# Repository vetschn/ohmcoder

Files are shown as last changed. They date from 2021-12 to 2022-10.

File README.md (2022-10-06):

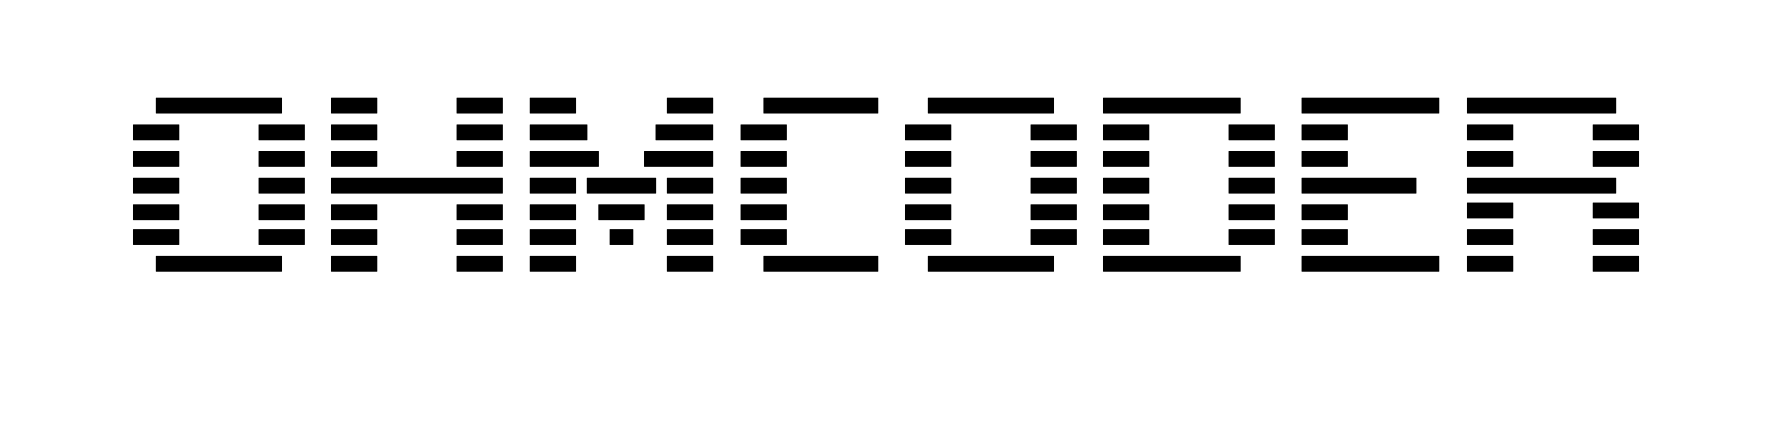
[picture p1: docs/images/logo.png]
ohmcoder
# 

The `OHMCODER` is a 16 channel fully analog vocoder, housed in a 3U 19"
enclosure with a full patch bay and feed-through functionality.

This project is inspired by [this](https://www.instructables.com/Build-an-analog-vocoder/) instructables project by user [planetone](https://www.instructables.com/member/planetone/).

## Overview

In vocoders, a program and carrier signal are filtered into a number of
frequency bands. The envelope of the program signal bands then modulates
the carrier signal bands. Finally, the per-band contributions are summed
back together to get the vocoded output.

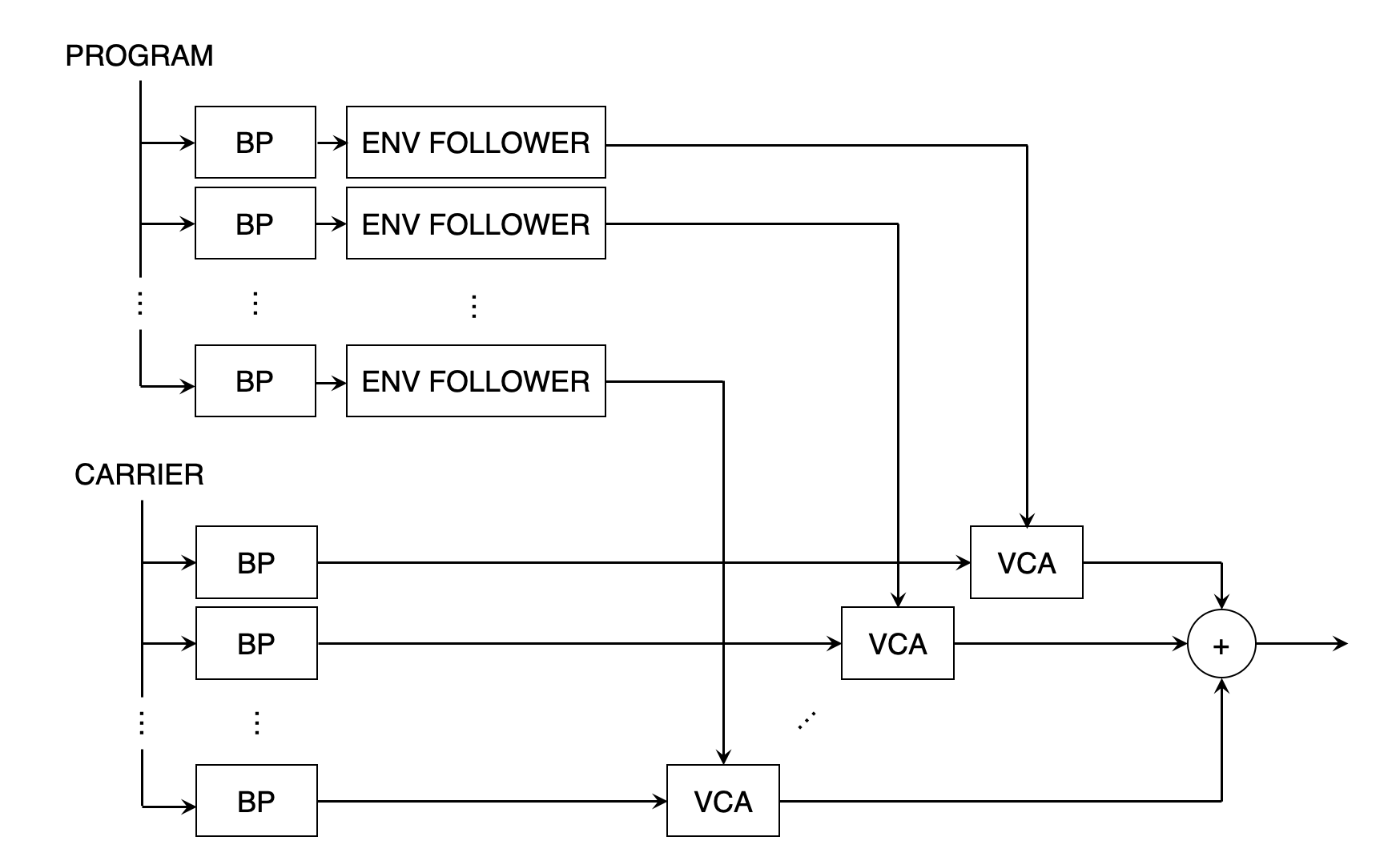
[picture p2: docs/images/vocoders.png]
vocoders


The core of the design thus made up of

- [Bandpass Filters](#multiple-feedback-infinite-gain-bandpass-filters)
- [Envelope Followers](#envelope-followers)
- [Voltage Controlled Amplifiers](#ota-voltage-controlled-amplifiers)

## Features

<!-- TODO -->

- Jack and XLR Input
- Patch Bay
- Per-Band Gain Control with LED Indicators
- Program or Carrier Band Feed-Through and/or Mixing
- Stereo and Mono Jack Output

## Circuits

### Multiple-Feedback Infinite Gain Bandpass Filters

We used the same second order multiple-feedback infinite-gain active
bandpass filters as in the instructibles project. TL074 quad opamps are
used.

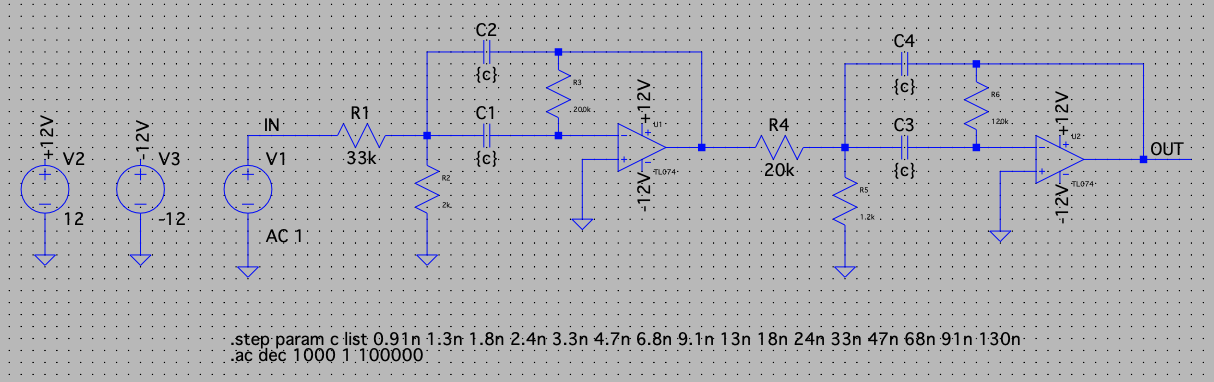
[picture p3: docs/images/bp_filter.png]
bp_filter


Notice, that the nice thing about these filters is, that we only need to
change the capacitor values to get different center frequencies, as seen
in the SPICE simulation below.

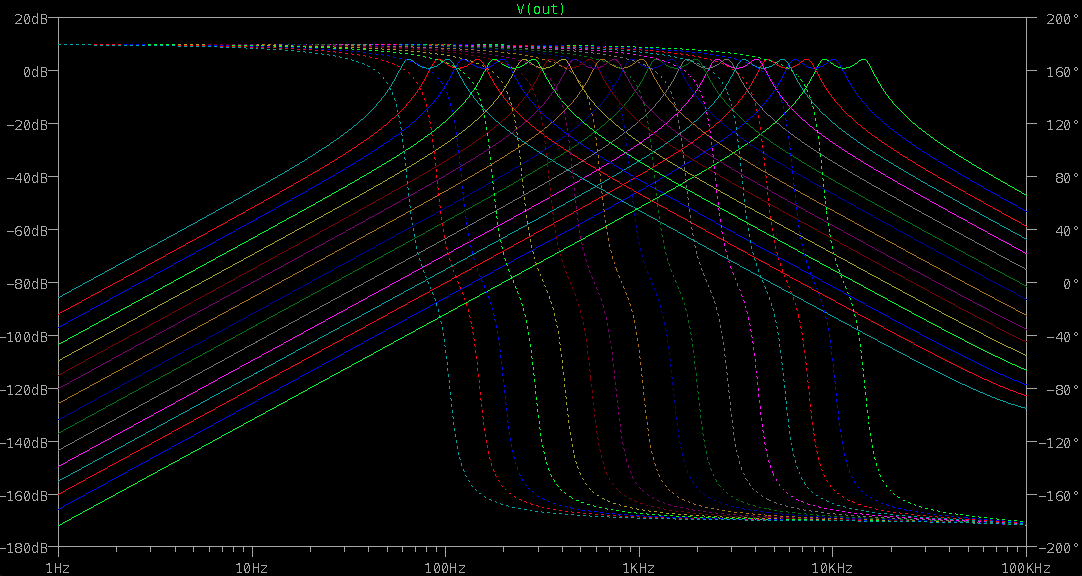
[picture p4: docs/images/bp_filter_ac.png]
bp_filter_ac


#### Capacitor Values

| Band | f_low [Hz] | f_high [Hz] | C [nF] |
| ---- | --- | --- | --- |
| 01 | 65 | 105 | 0.91 |
| 02 | 90 | 150 | 1.3 |
| 03 | 125 | 200 | 1.8 |
| 04 | 175 | 285 | 2.4 |
| 05 | 255 | 400 | 3.3 |
| 06 | 345 | 555 | 4.7 |
| 07 | 465 | 755 | 6.8 |
| 08 | 635 | 1050 | 9.1 |
| 09 | 920 | 1455 | 13 |
| 10 | 1220 | 1960 | 18 |
| 11 | 1765 | 2880 | 24 |
| 12 | 2500 | 4075 | 33 |
| 13 | 3515 | 5605 | 47 |
| 14 | 4640 | 7550 | 68 |
| 15 | 6375 | 10375 | 91 |
| 16 | 9200 | 15000 | 130 |

### Envelope Followers

This is where we depart from planetone's design. We use a low-pass
filtered precision rectifier signal to follow the program envelope.

The majority of the spectral energy of speech amplitude modulation lies
below about 15Hz, i. e. the mean time between syllables is about
1/15Hz (see [speech_modulation.ipynb](./auxiliary/notebooks/speech_modulation.ipynb) for an example). The filter is chosen such that we follow this
amplitude modulation.

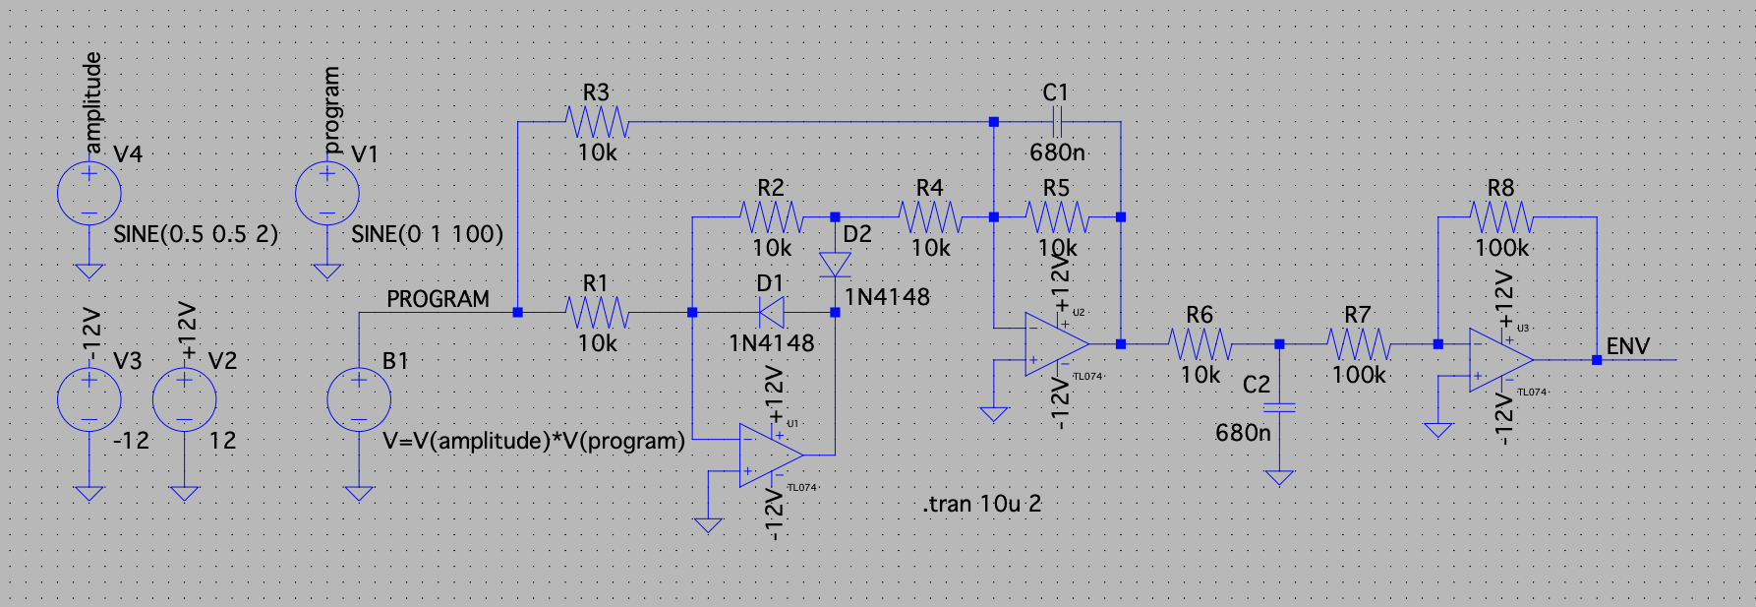
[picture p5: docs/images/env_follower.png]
env_follower


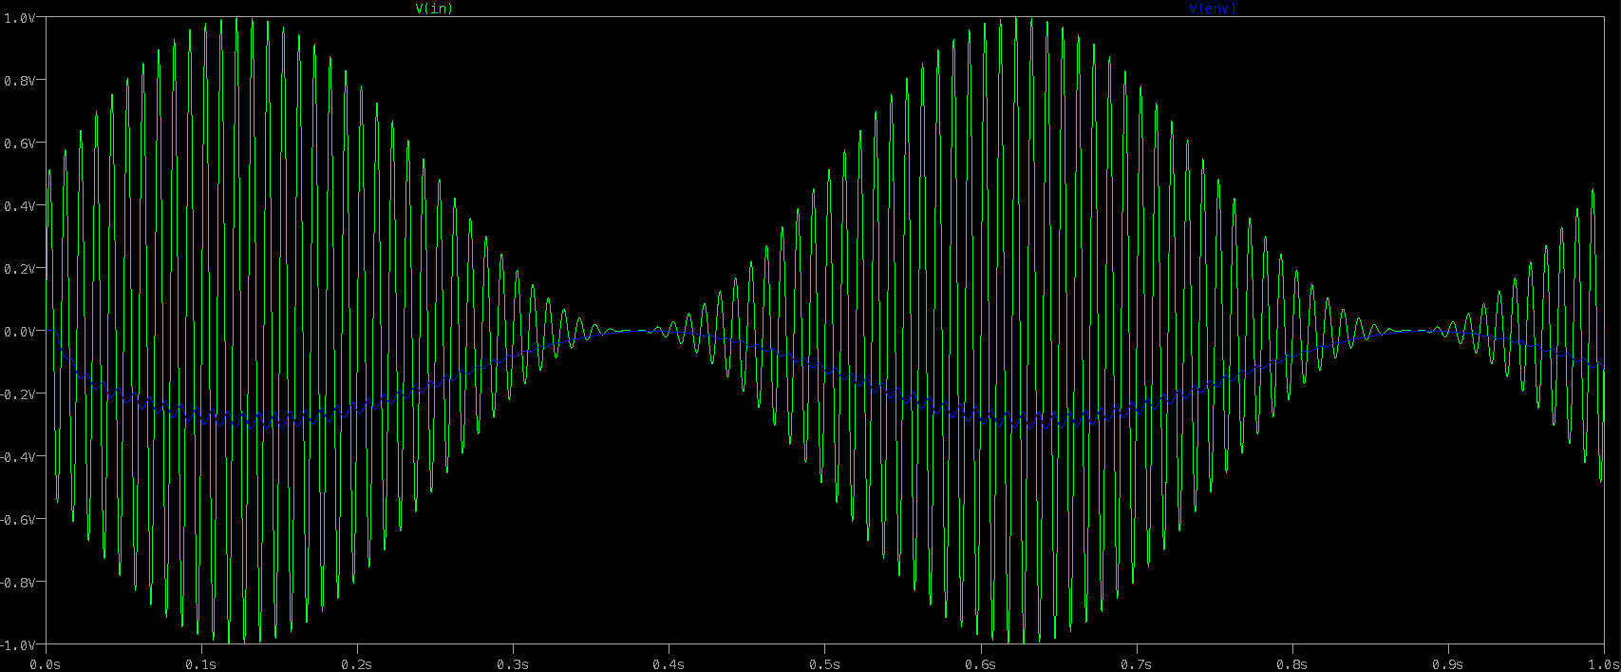
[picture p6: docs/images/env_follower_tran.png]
env_follower_tran


### OTA Voltage Controlled Amplifiers

We use VCAs based on the LM13700 quad operational transconductance
amplifier, making use of its linearizing diodes and the integrated
buffer circuits.

The program envelope controls the amplifier gain via a voltage to
current converter circuit.

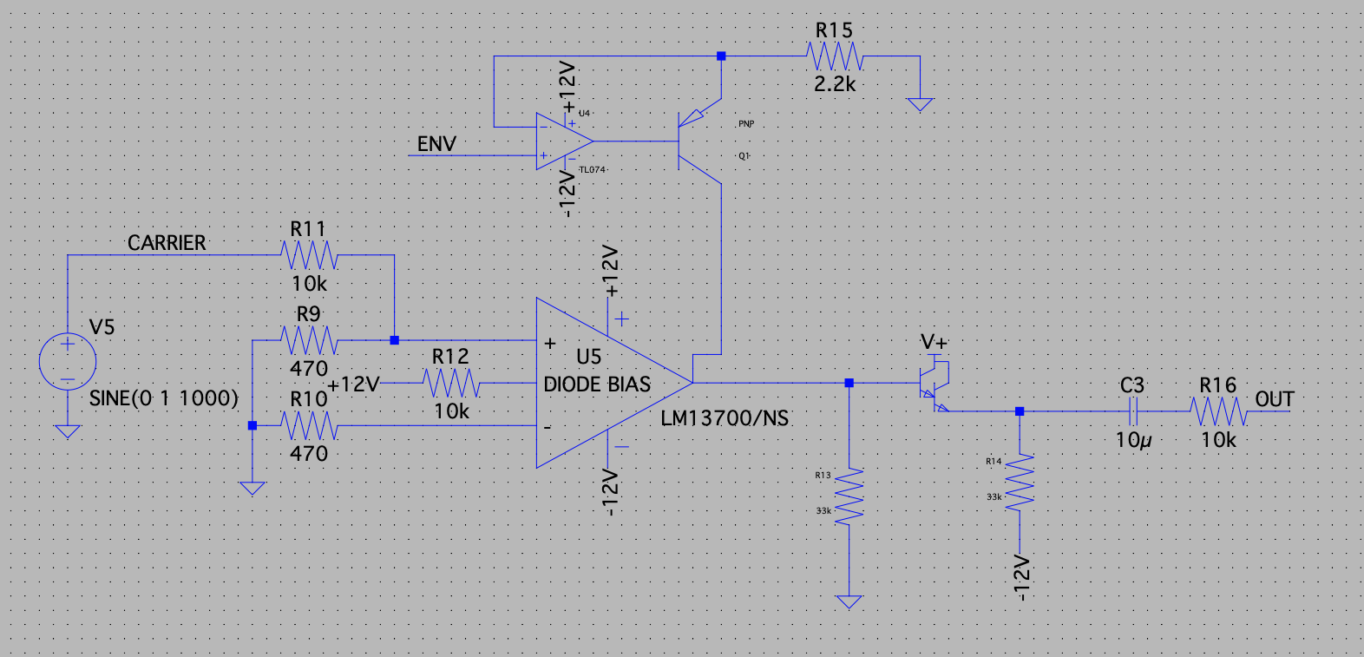
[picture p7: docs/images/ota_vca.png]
ota_vca


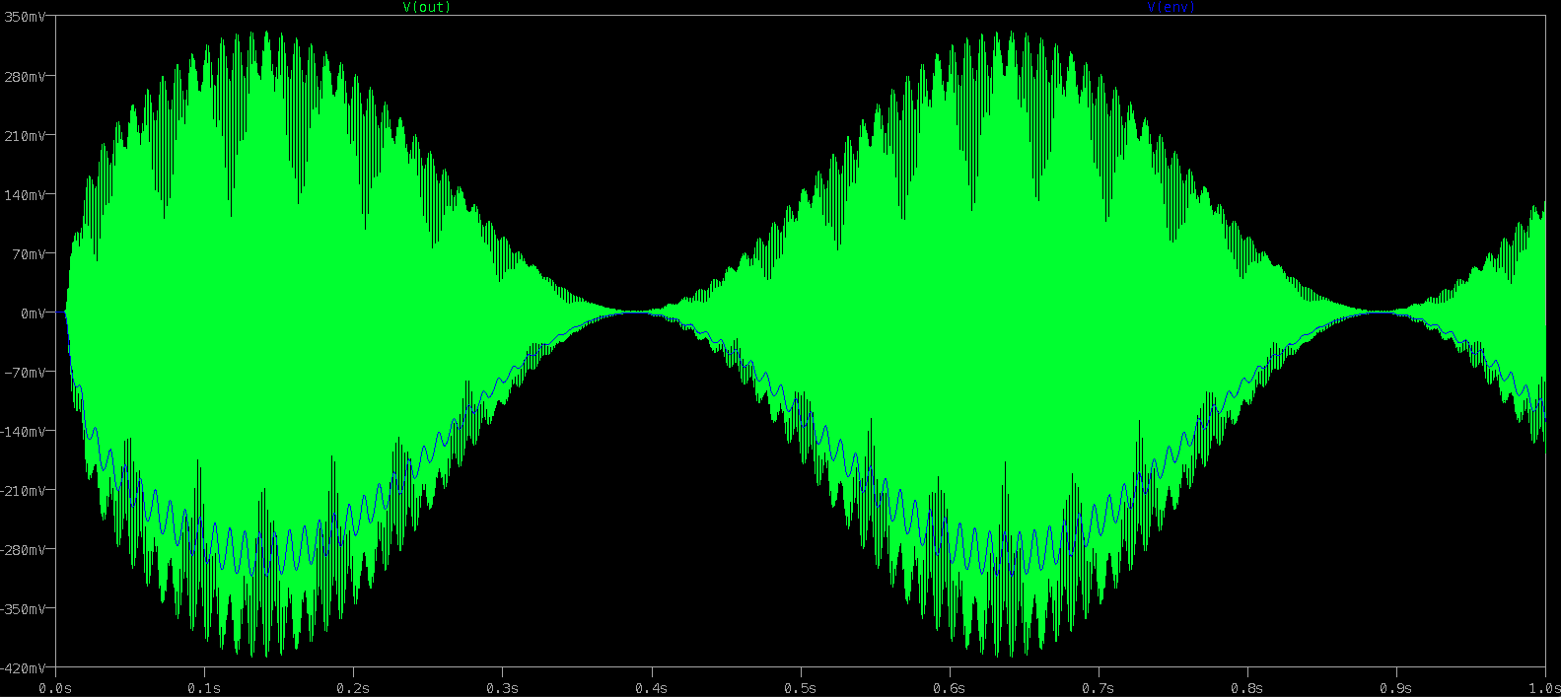
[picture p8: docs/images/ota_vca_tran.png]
ota_vca_tran


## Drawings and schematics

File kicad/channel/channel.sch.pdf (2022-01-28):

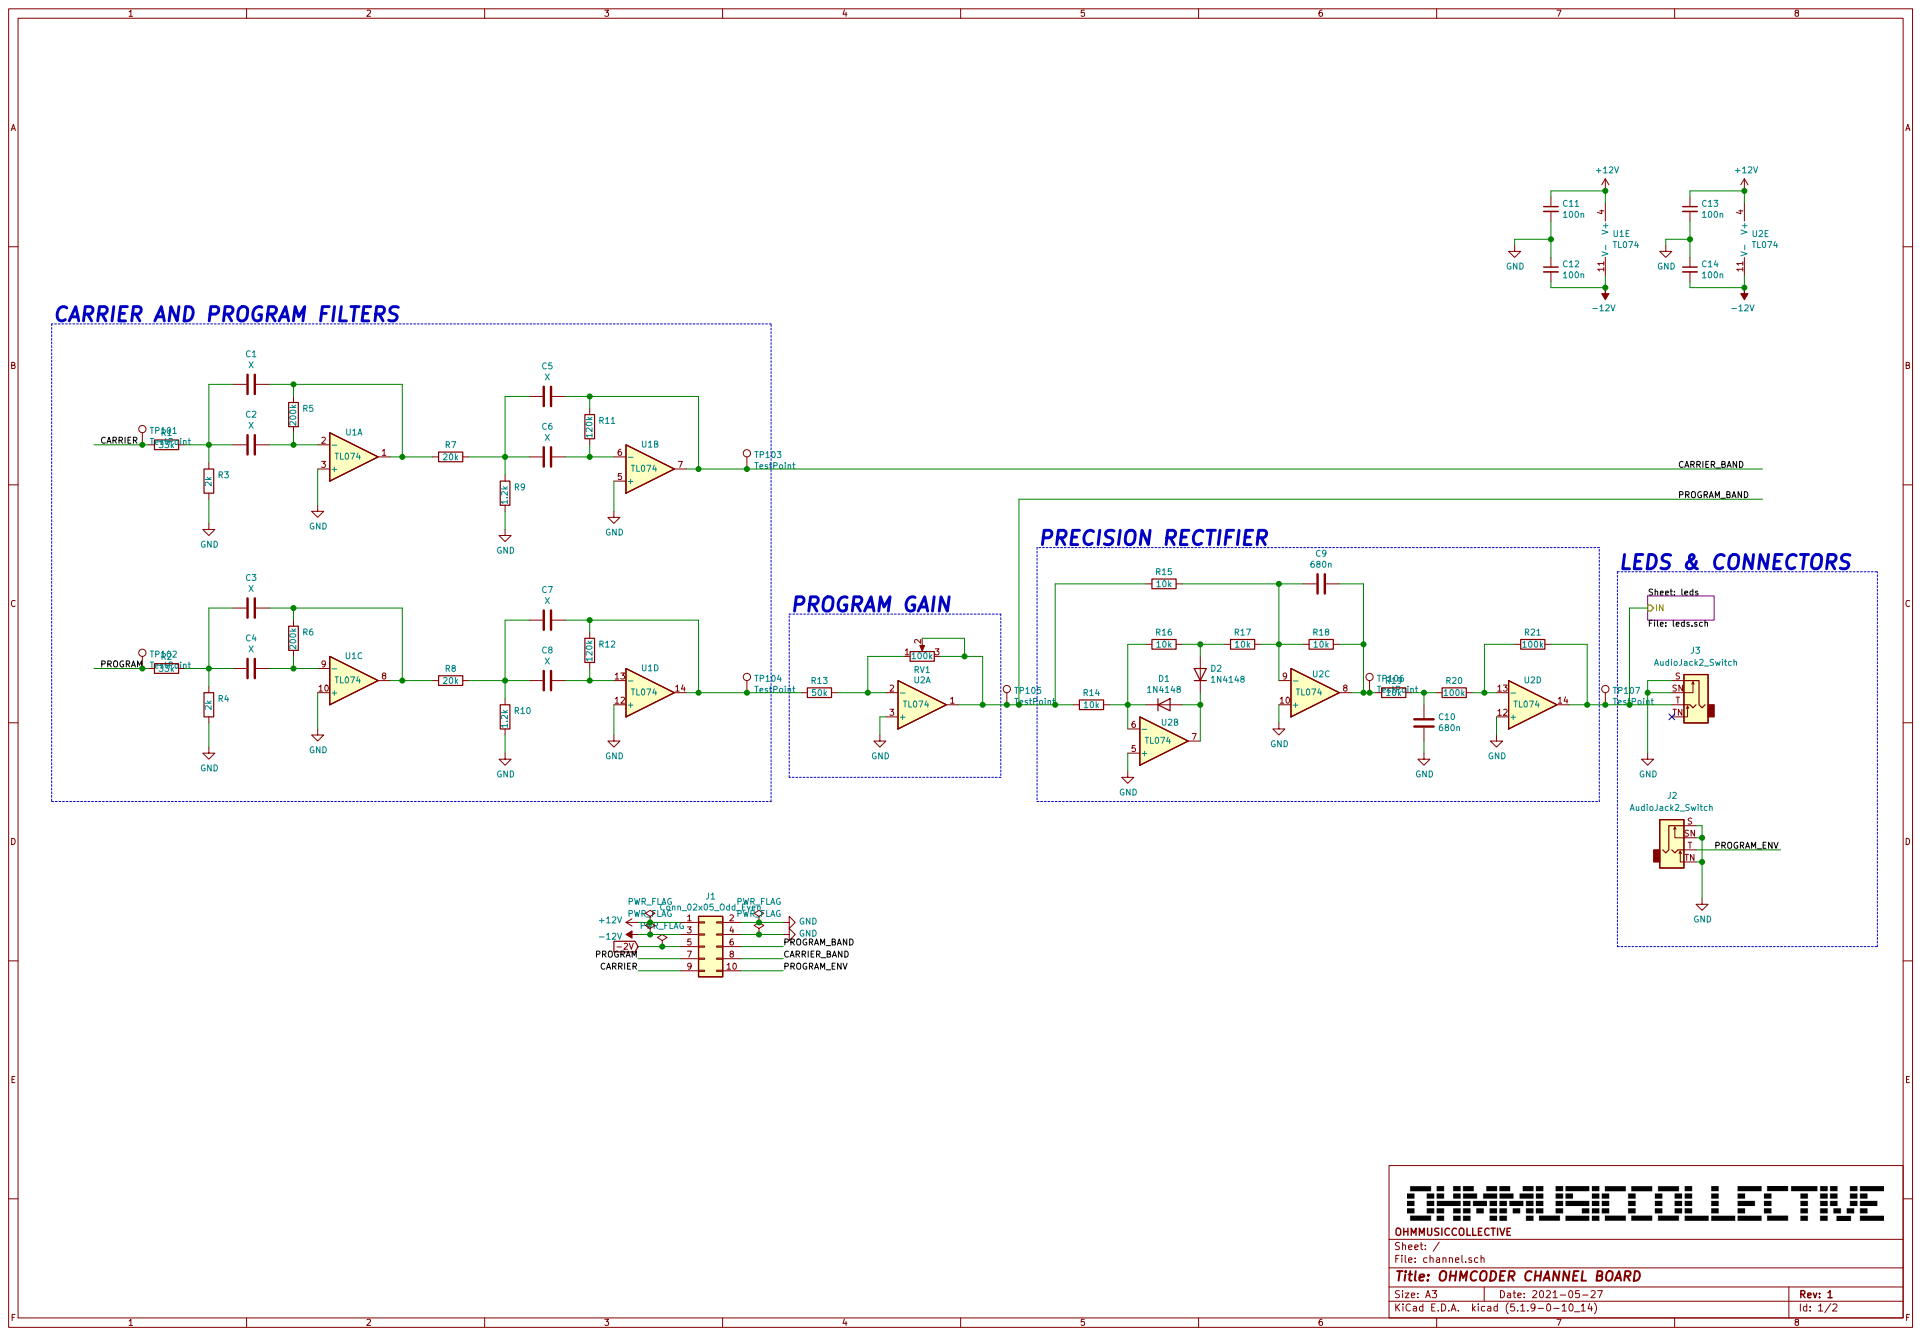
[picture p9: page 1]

PROGRAM_BAND CARRIER AND PROGRAM FILTERS

Sheet: leds File: leds.sch

File: channel.sch Sheet: / OHMMUSICCOLLECTIVE

Id: 1/2 Title: OHMCODER CHANNEL BOARD

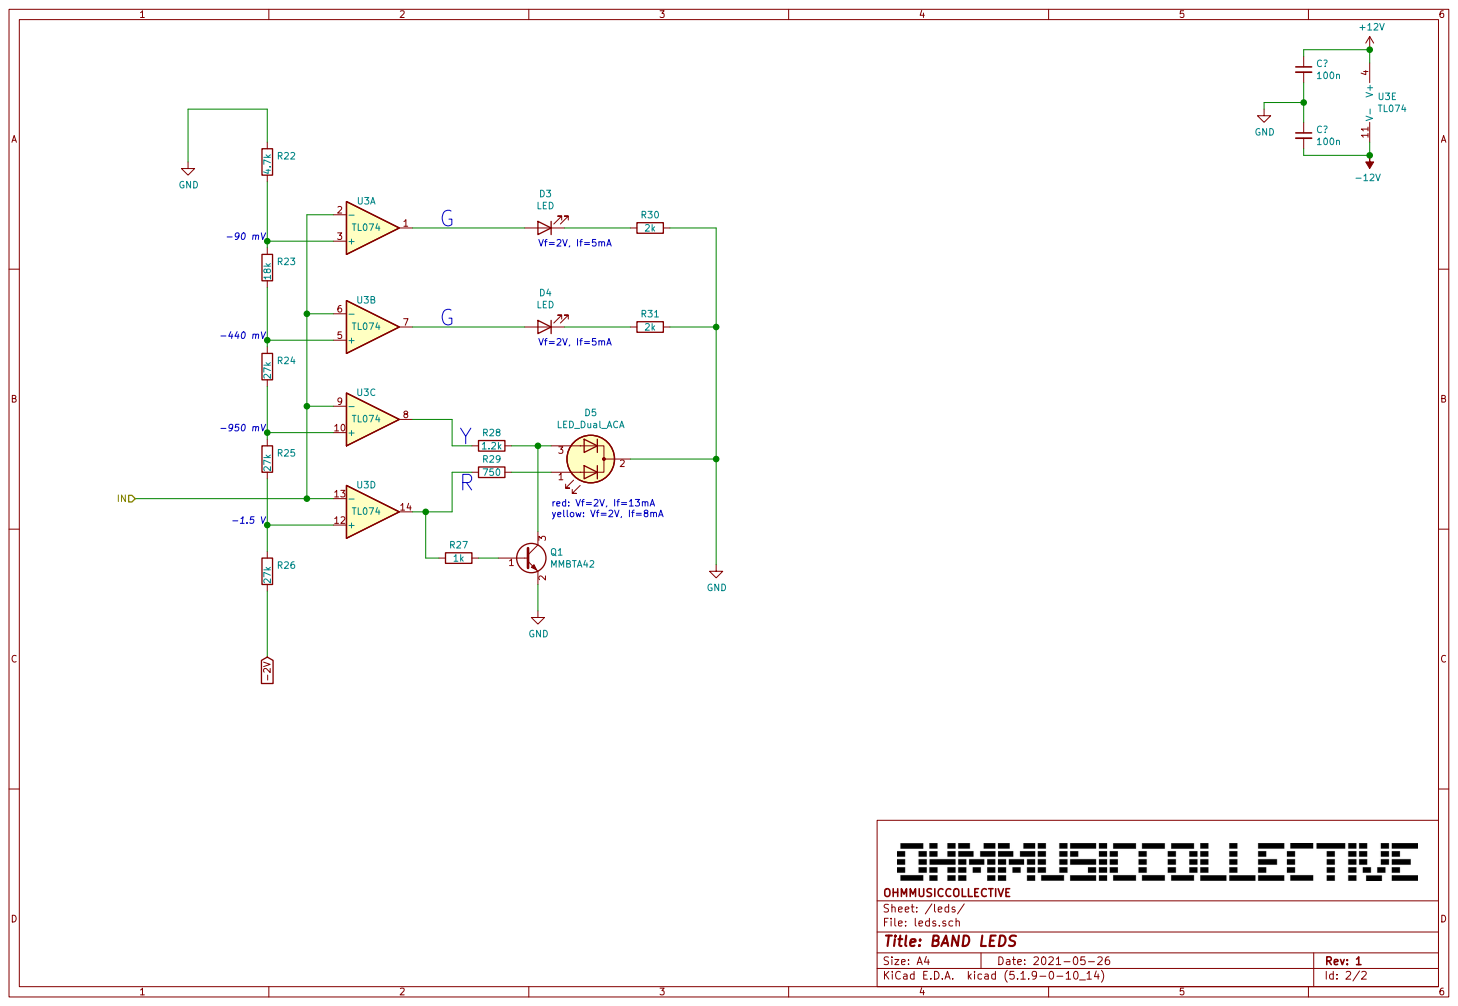
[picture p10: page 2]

File: leds.sch Sheet: /leds/ OHMMUSICCOLLECTIVE

Id: 2/2 Title: BAND LEDS

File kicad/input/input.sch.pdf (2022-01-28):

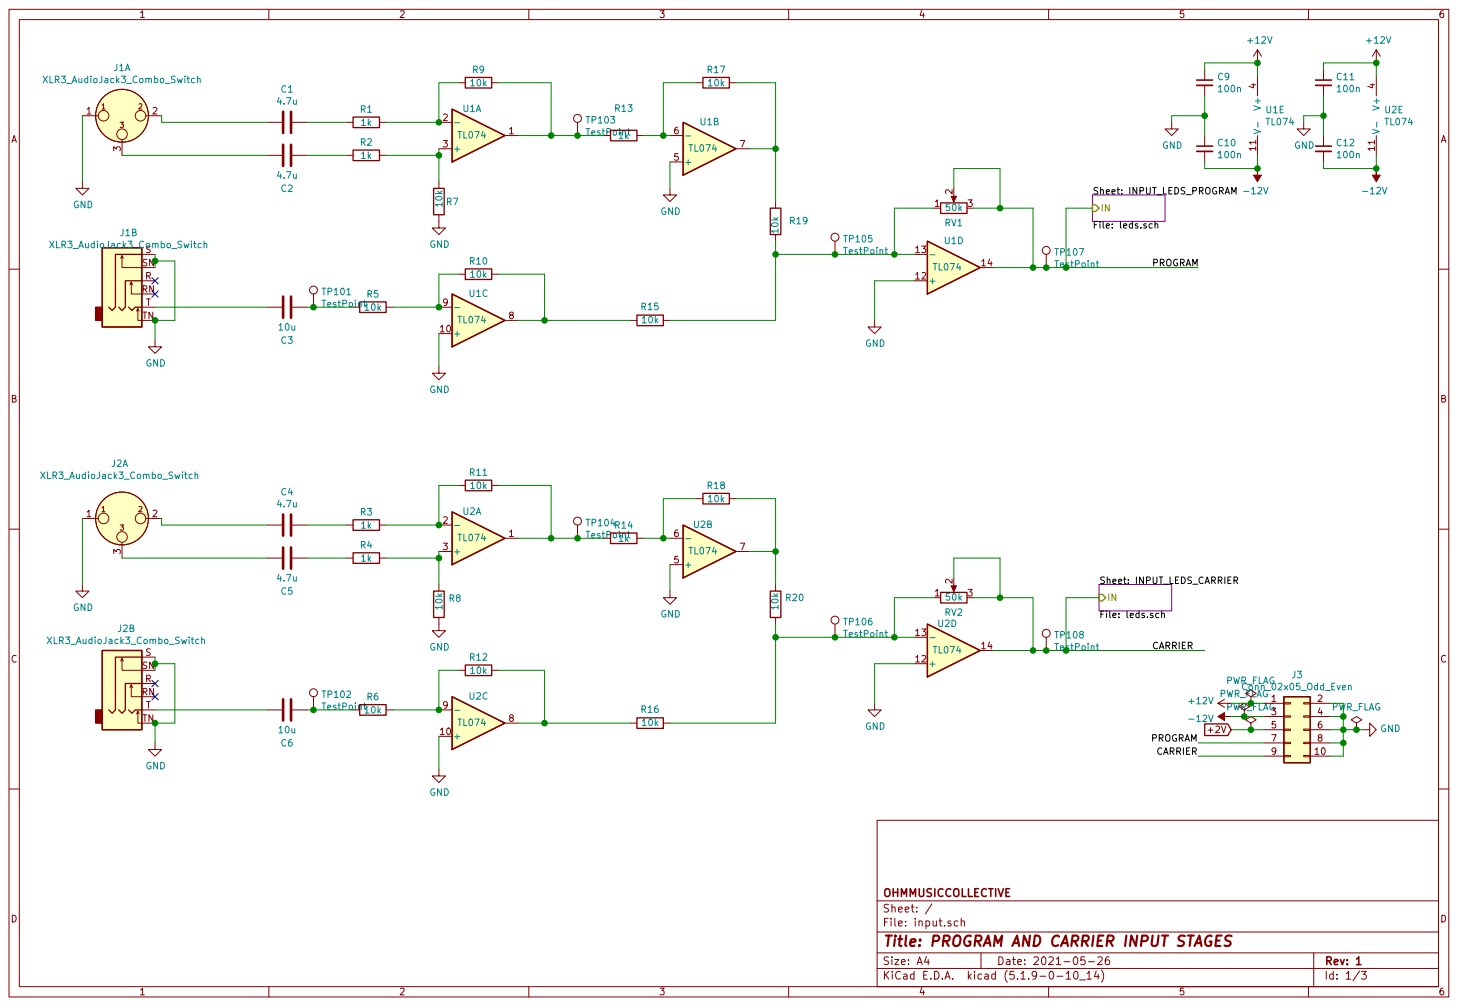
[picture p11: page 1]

File: input.sch Sheet: / OHMMUSICCOLLECTIVE

Id: 1/3 Title: PROGRAM AND CARRIER INPUT STAGES

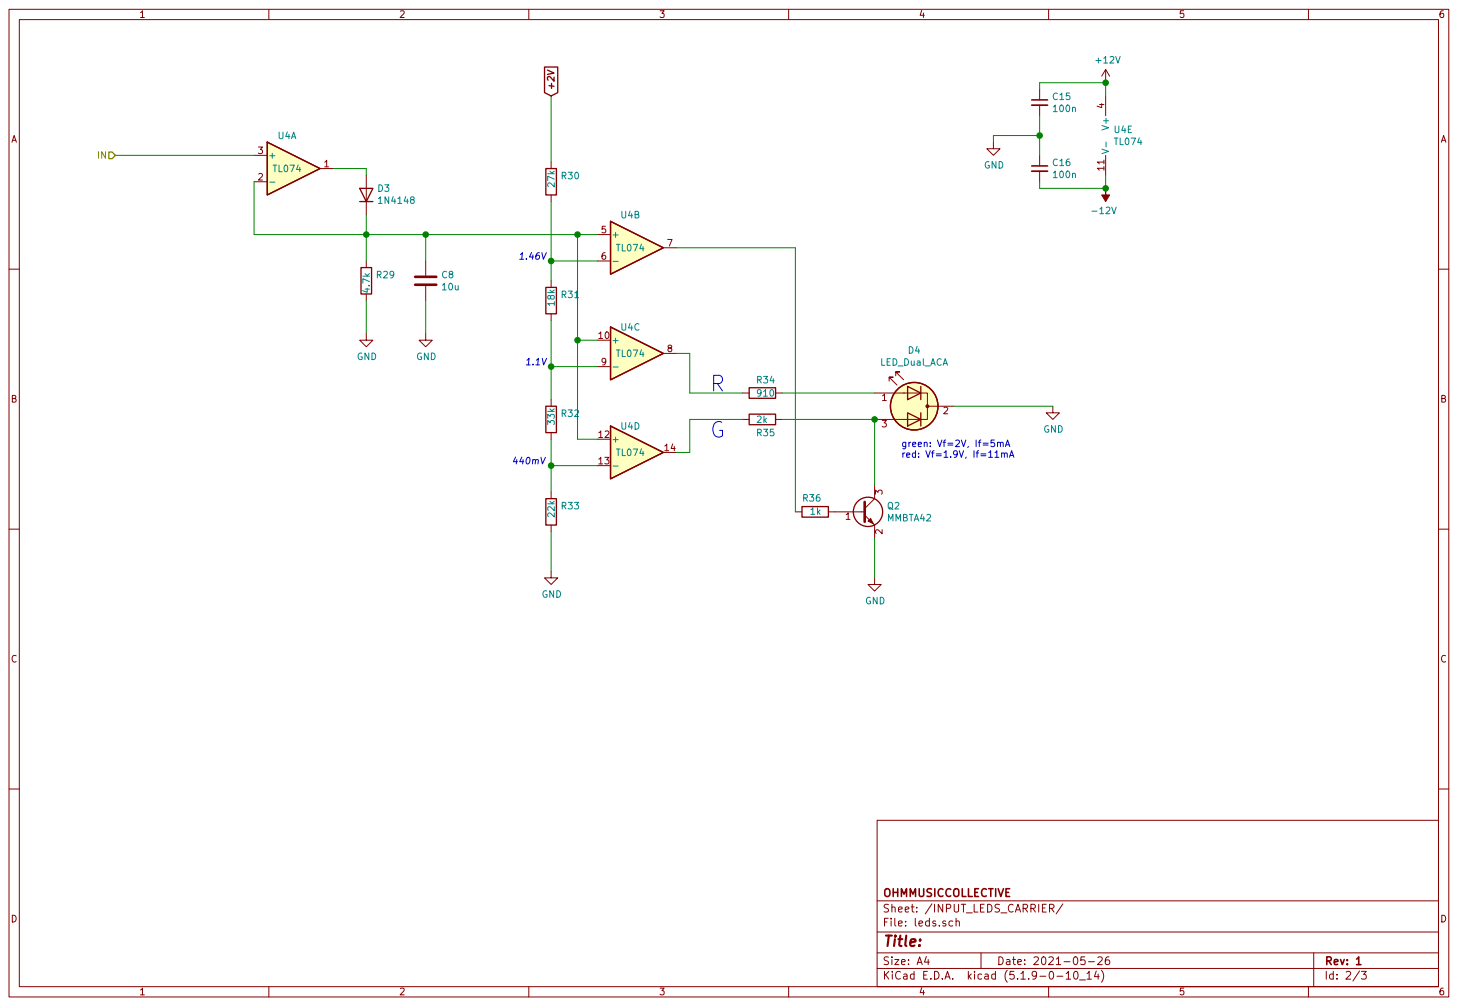
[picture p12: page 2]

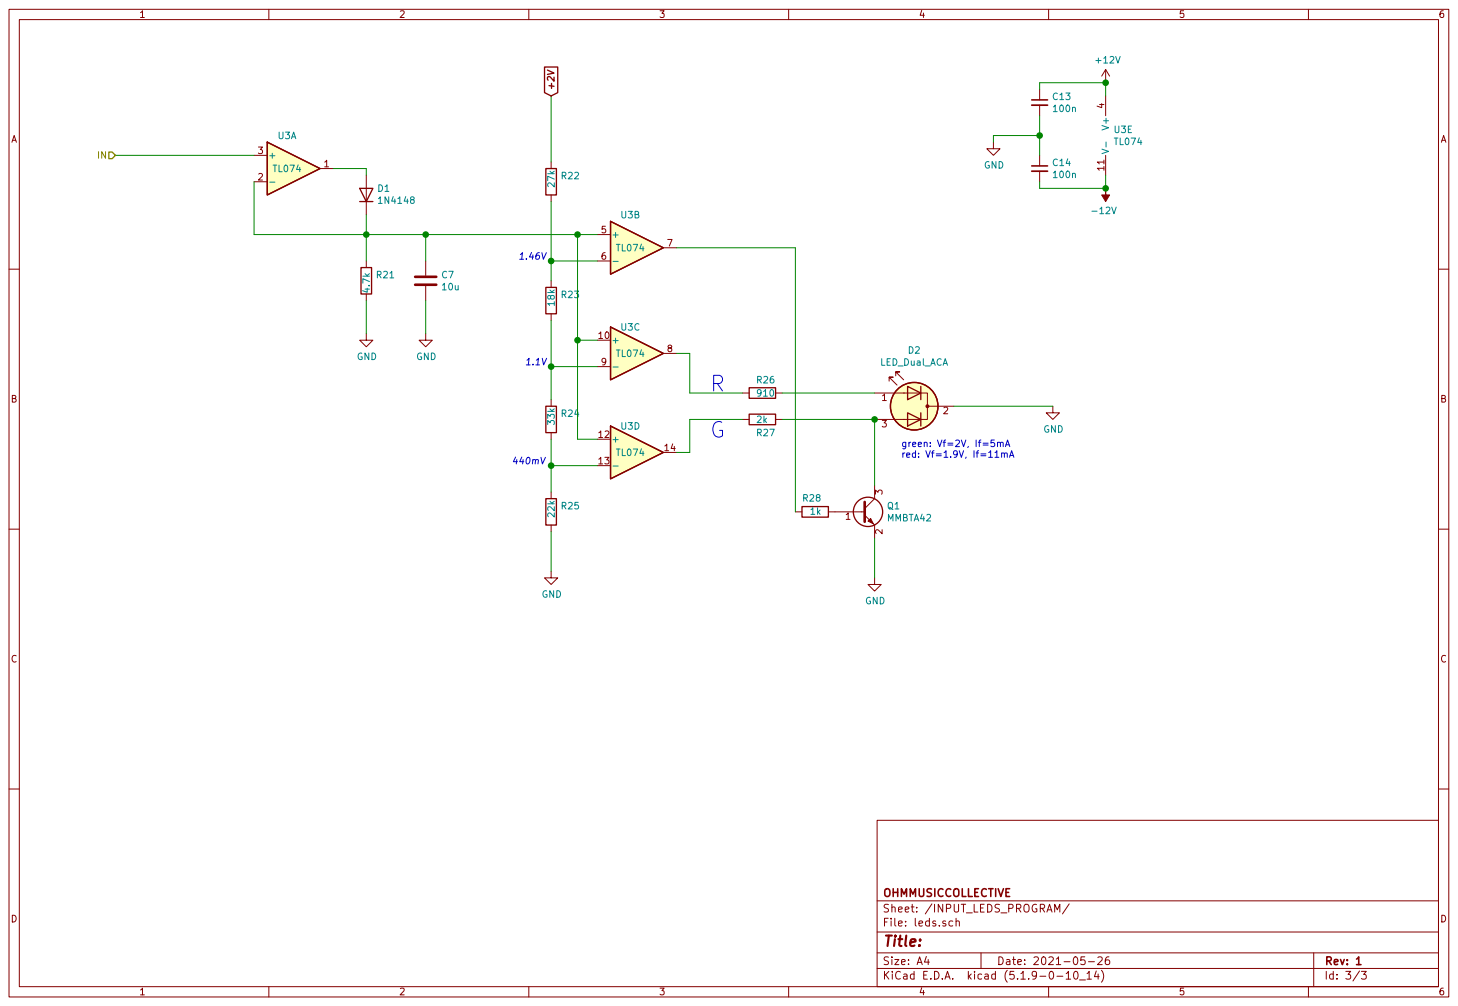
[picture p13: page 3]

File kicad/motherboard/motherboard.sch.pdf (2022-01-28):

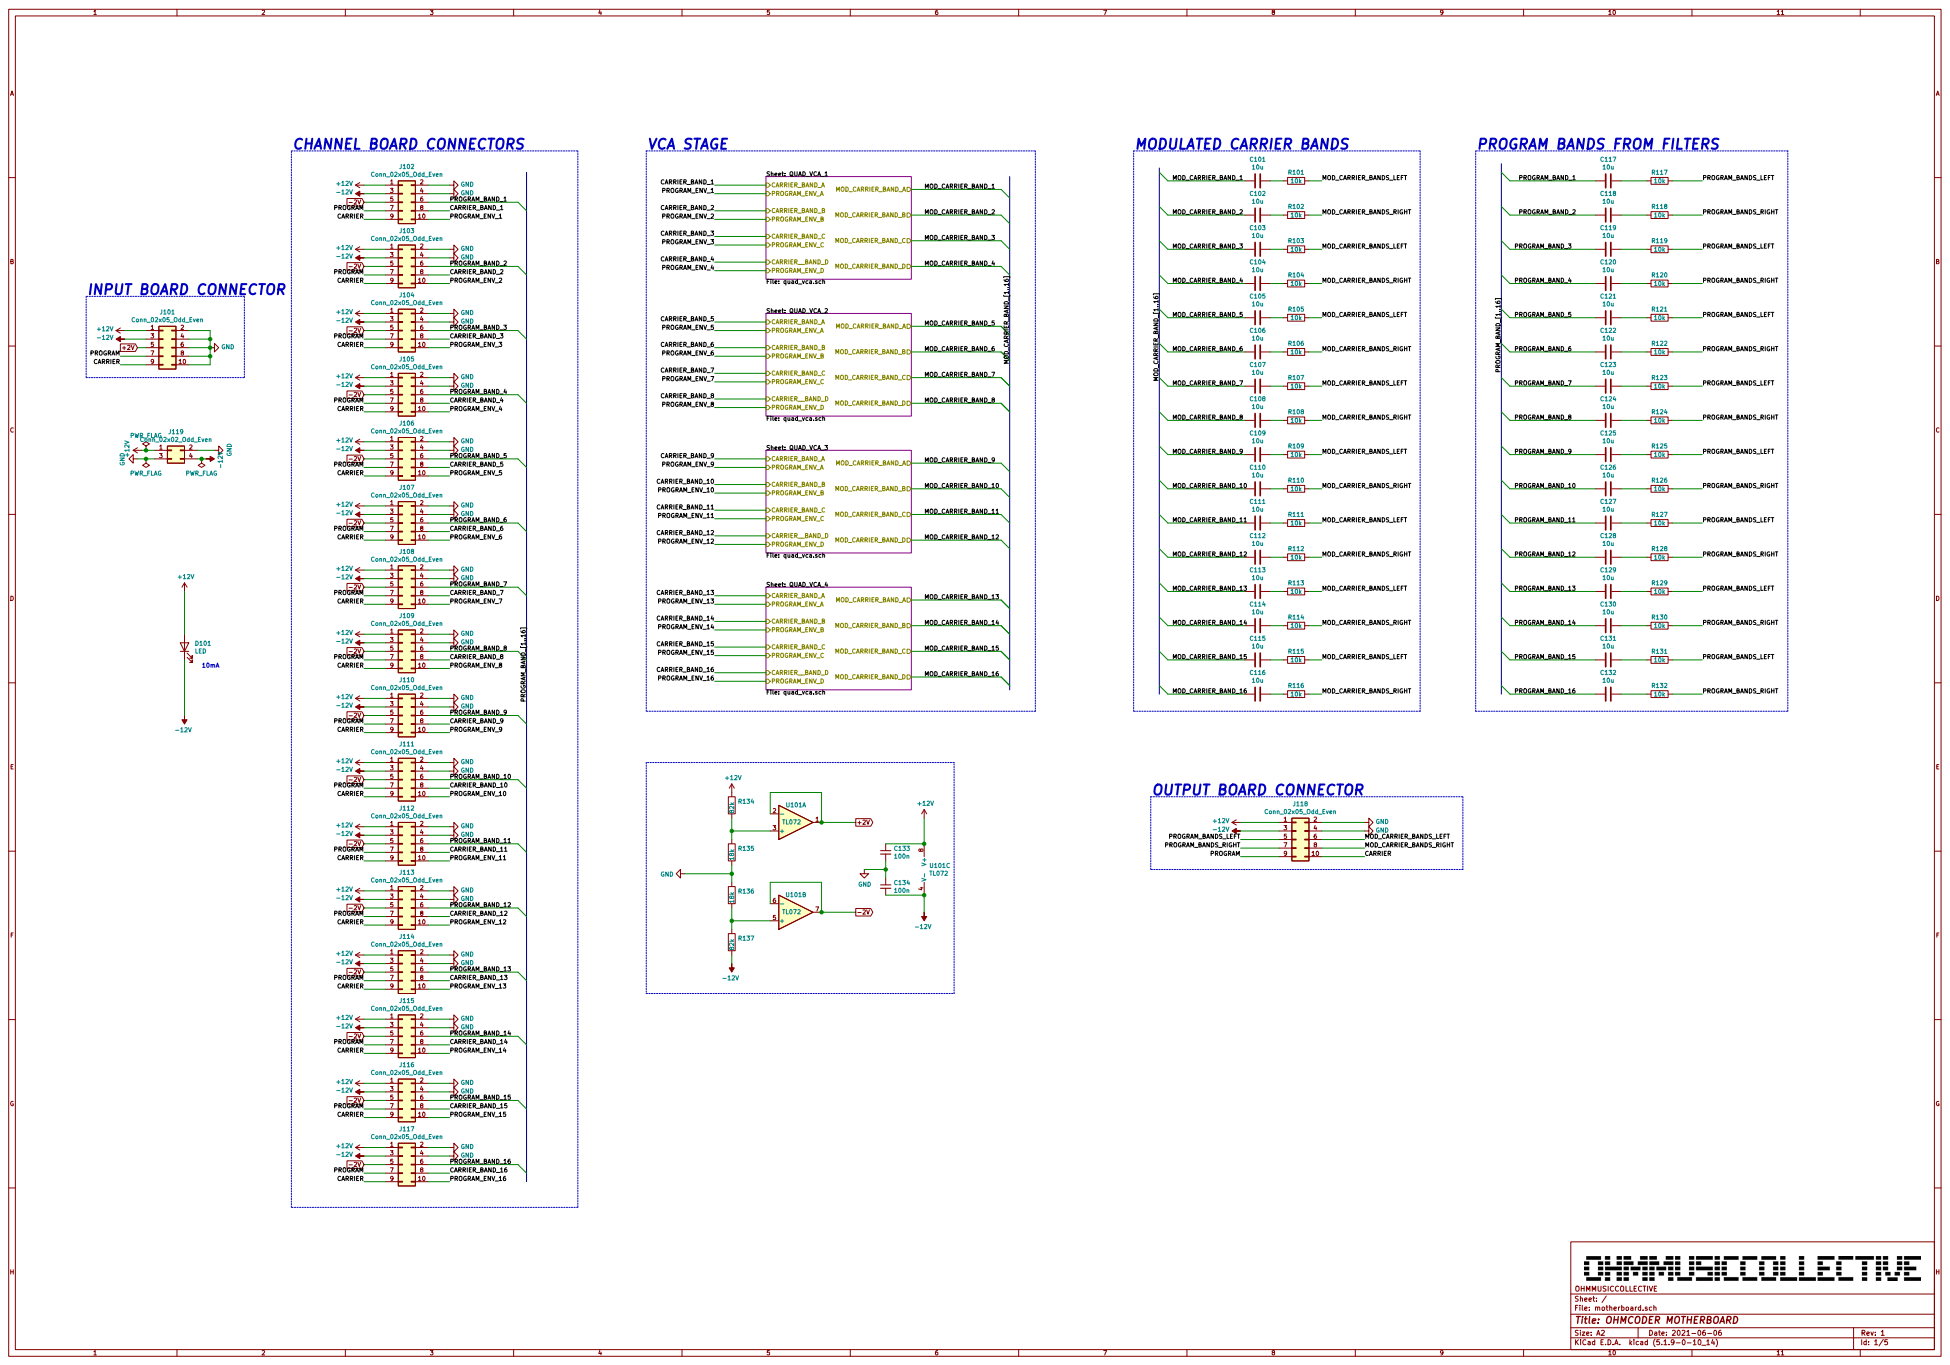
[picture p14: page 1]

File: motherboard.sch Sheet: / OHMMUSICCOLLECTIVE

Id: 1/5 Title: OHMCODER MOTHERBOARD

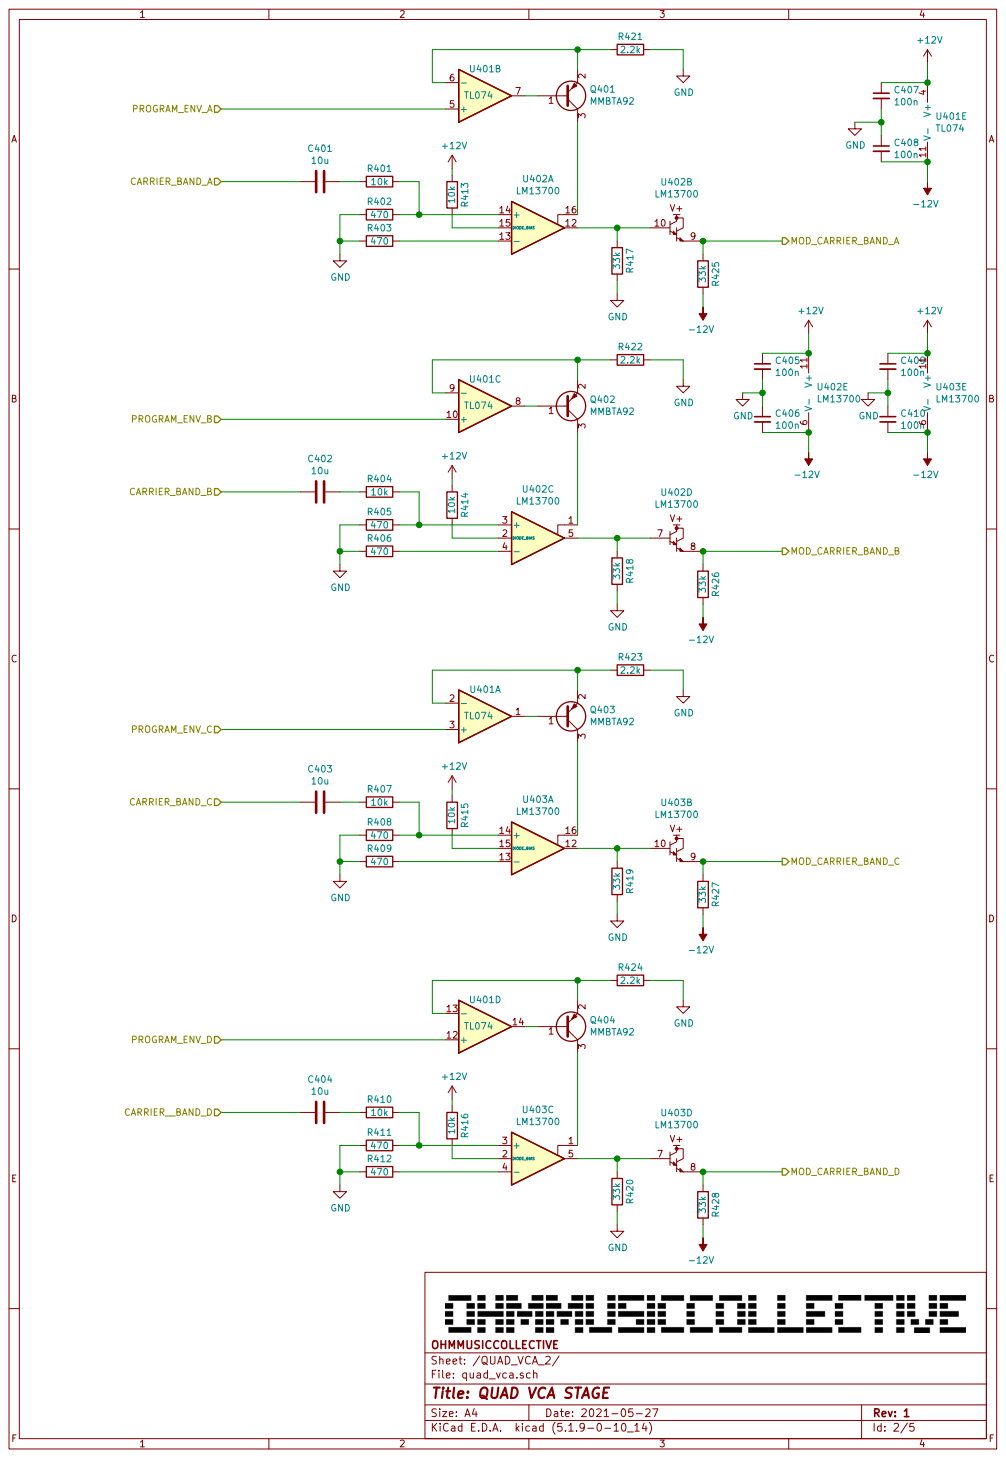
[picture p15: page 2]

File: quad_vca.sch
Id: 2/5 Title: QUAD VCA STAGE

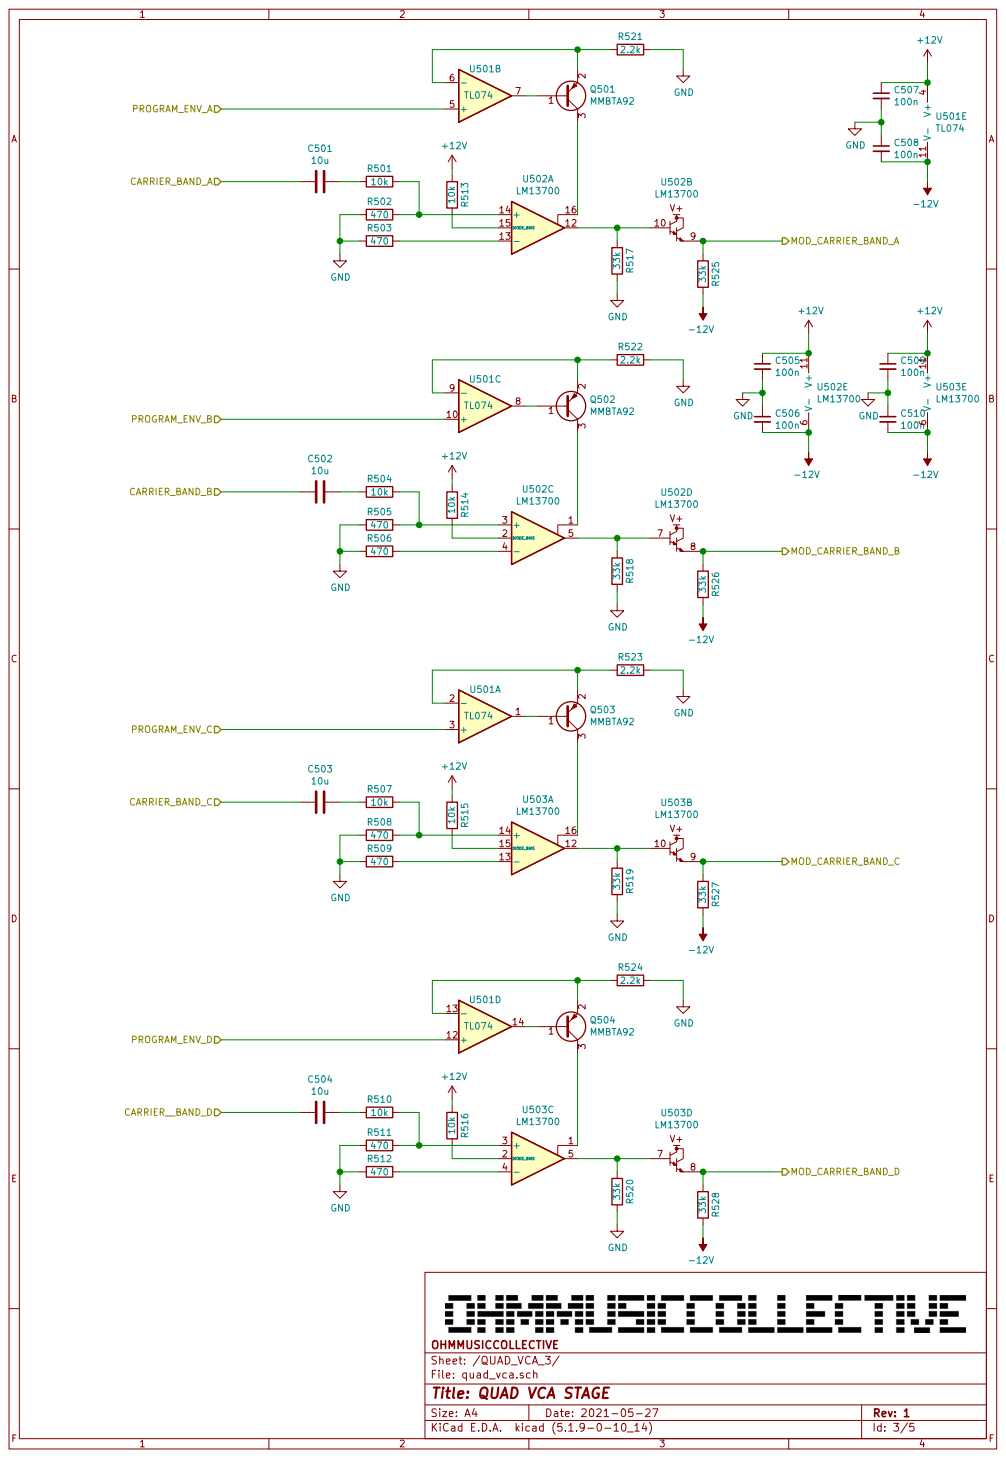
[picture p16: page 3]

Id: 3/5 Title: QUAD VCA STAGE

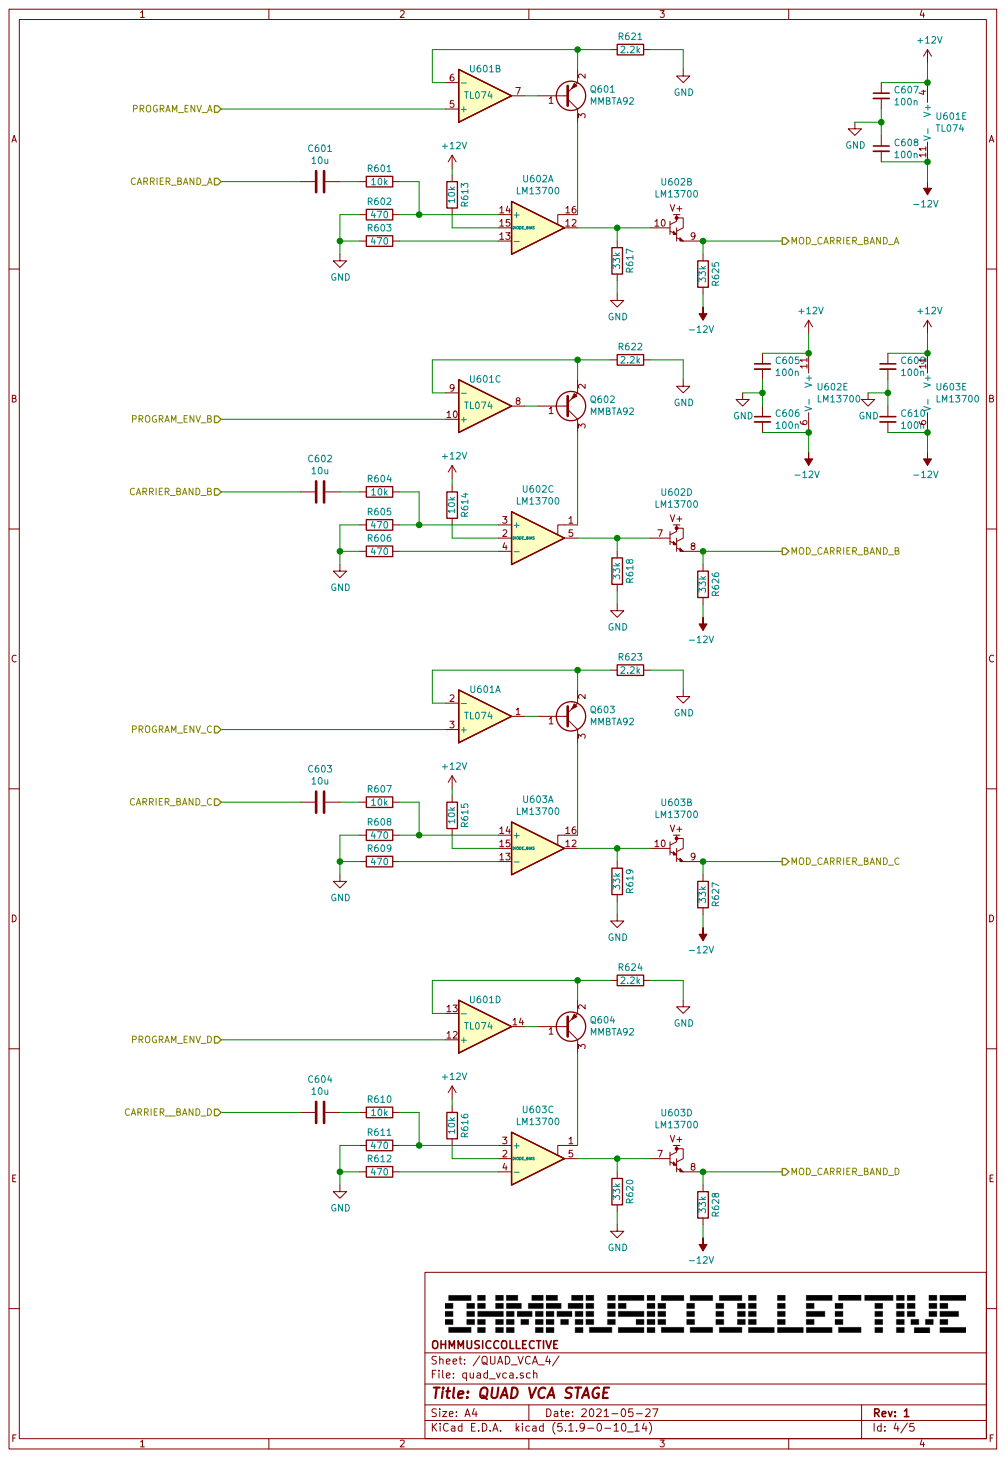
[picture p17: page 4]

Id: 4/5 Title: QUAD VCA STAGE

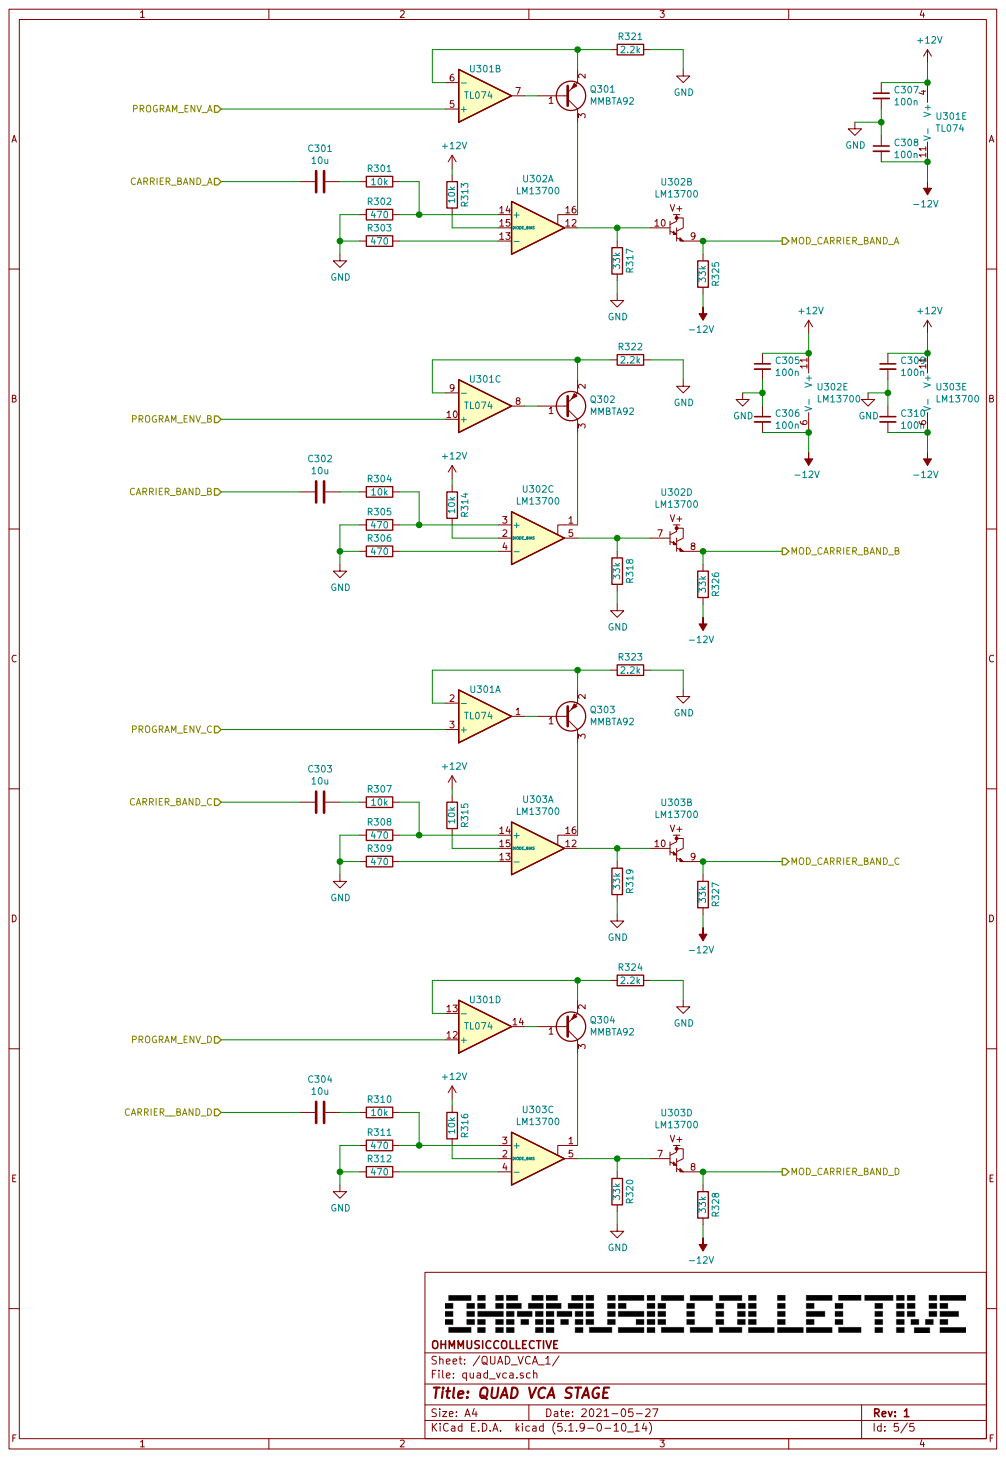
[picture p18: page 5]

Id: 5/5 Title: QUAD VCA STAGE

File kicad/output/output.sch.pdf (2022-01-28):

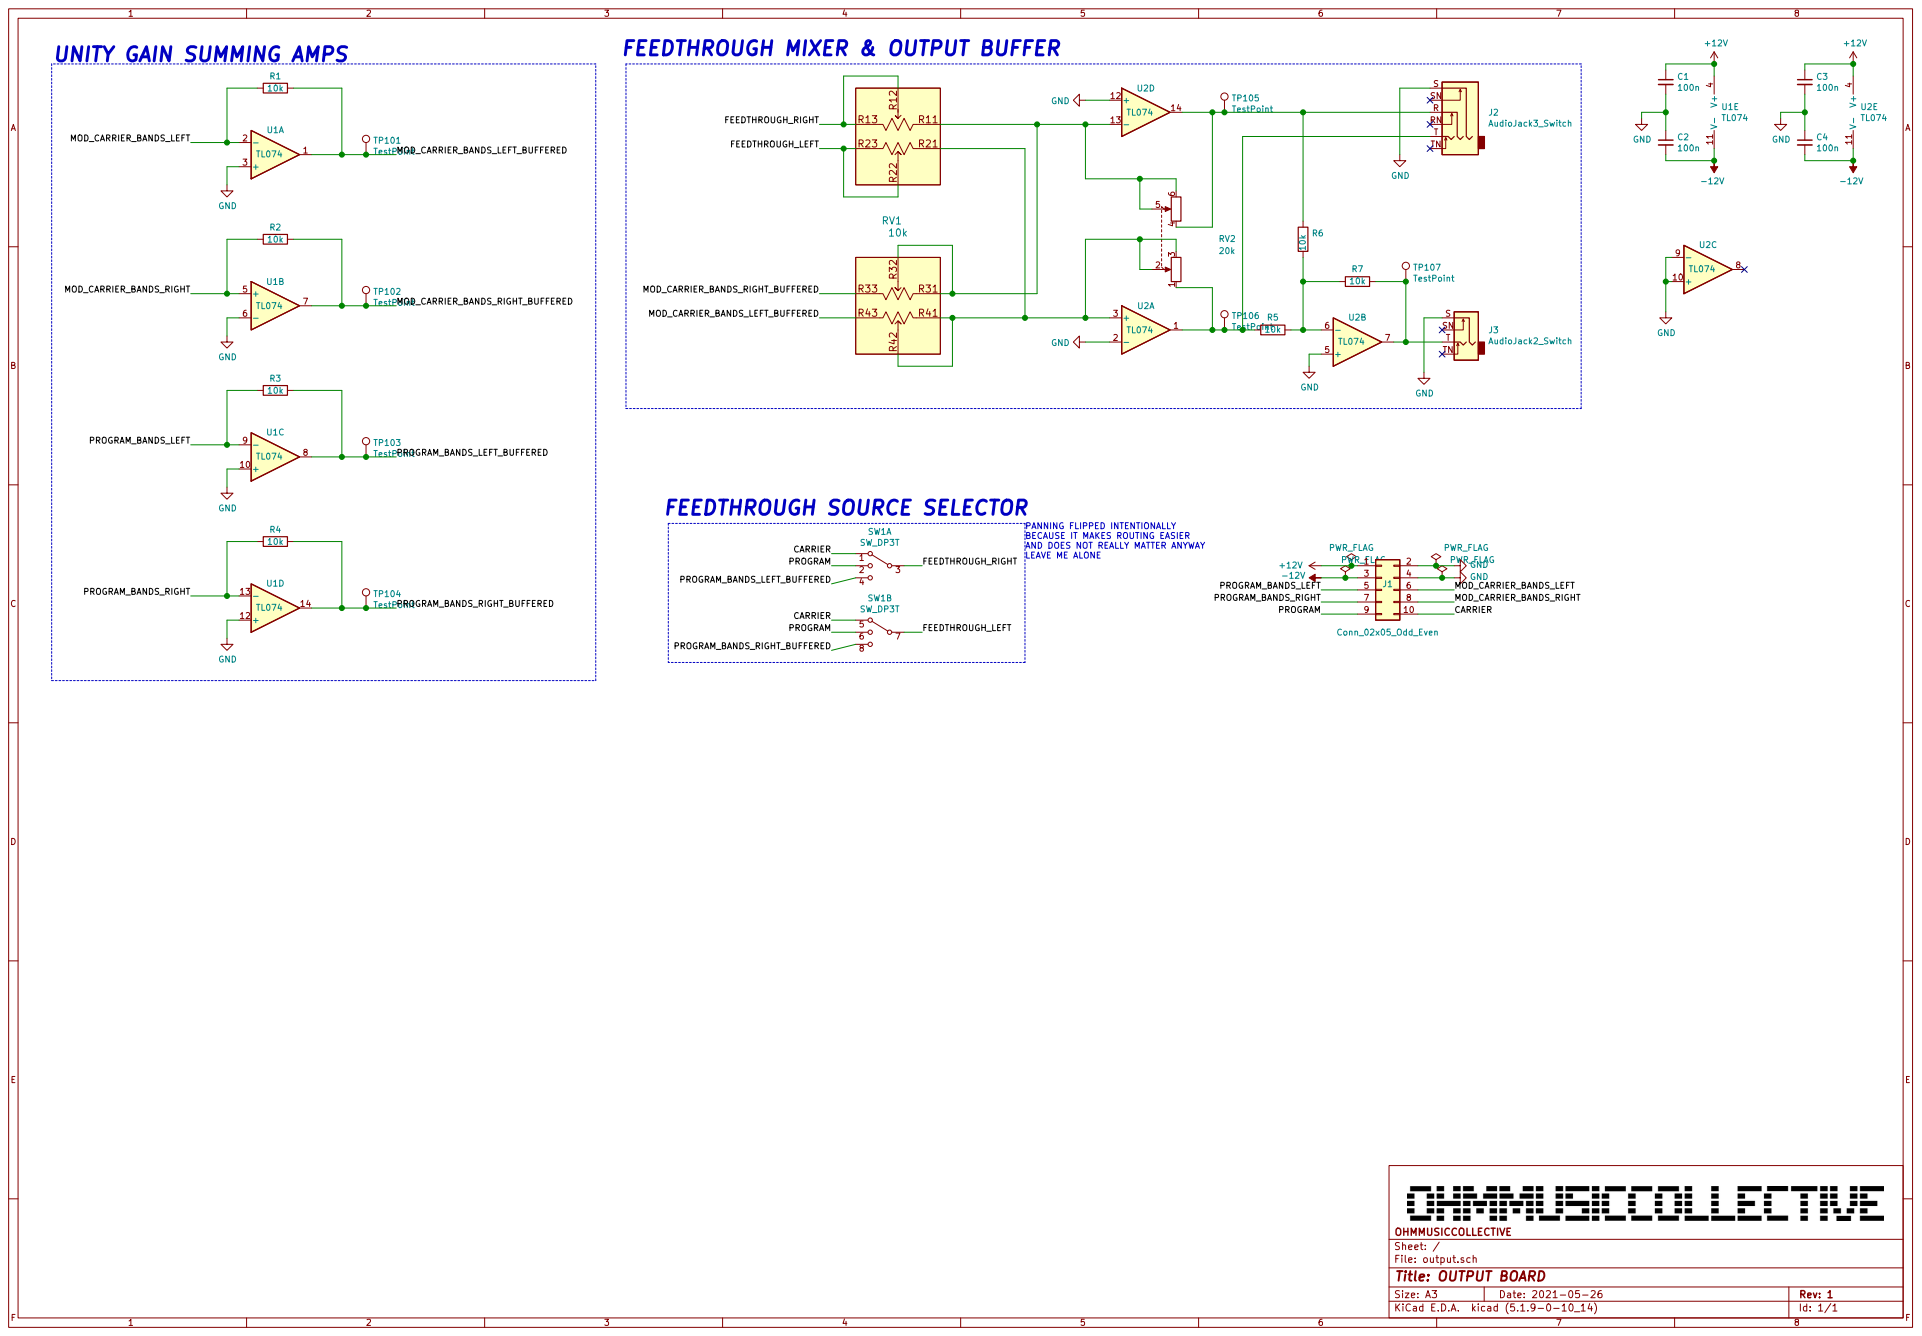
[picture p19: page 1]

File: output.sch Sheet: / OHMMUSICCOLLECTIVE

Id: 1/1 Title: OUTPUT BOARD

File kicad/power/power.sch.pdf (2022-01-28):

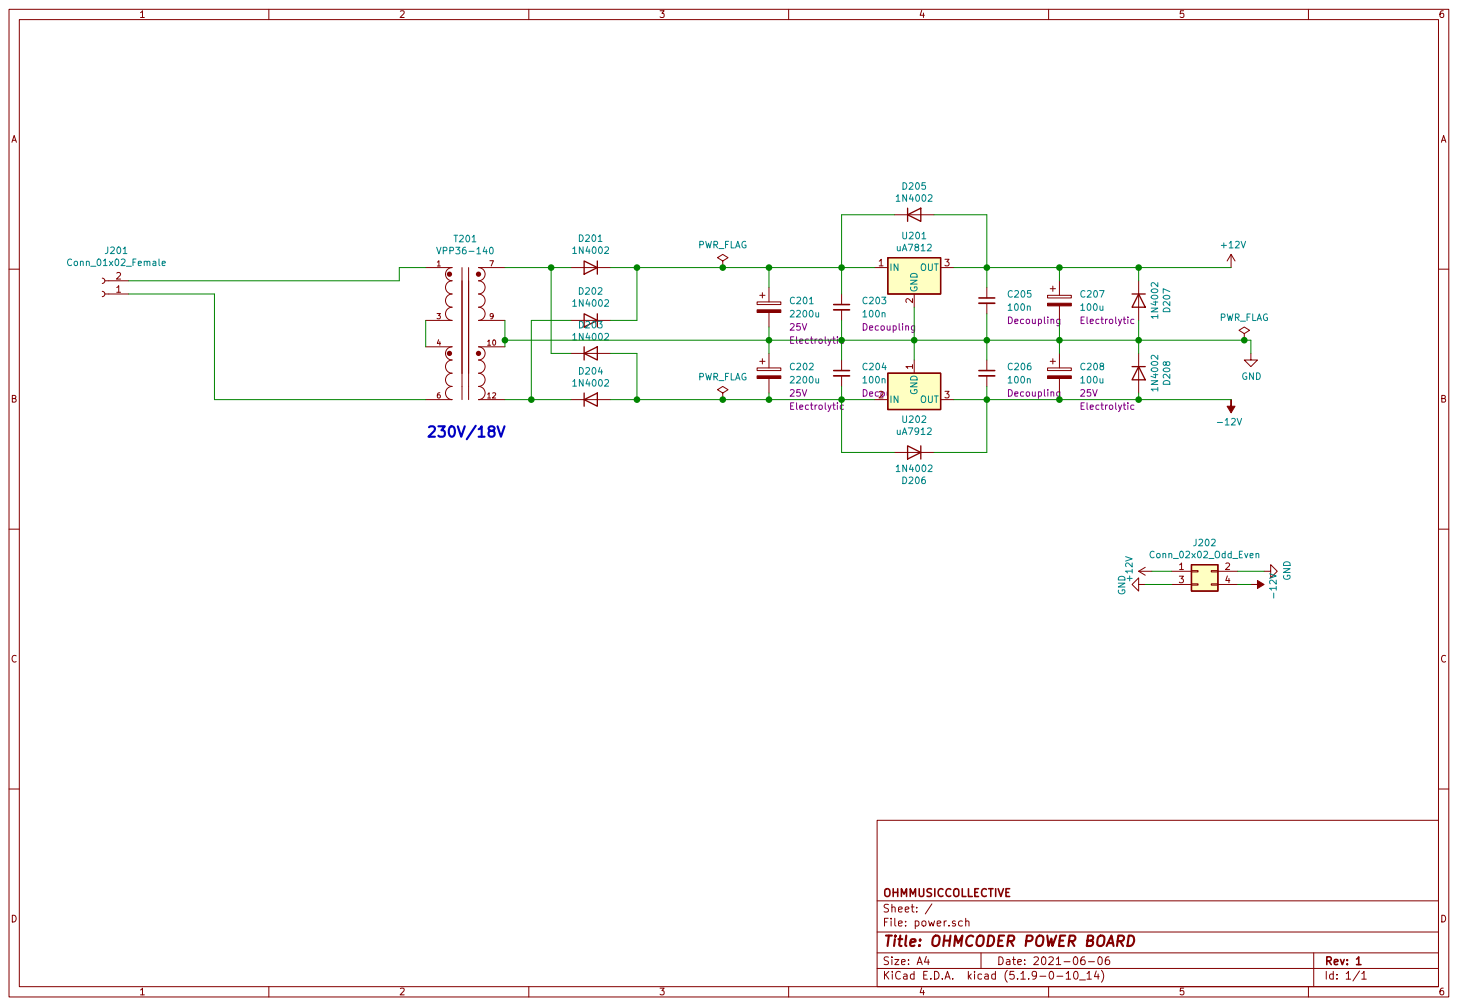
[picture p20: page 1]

Id: 1/1 Title: OHMCODER POWER BOARD

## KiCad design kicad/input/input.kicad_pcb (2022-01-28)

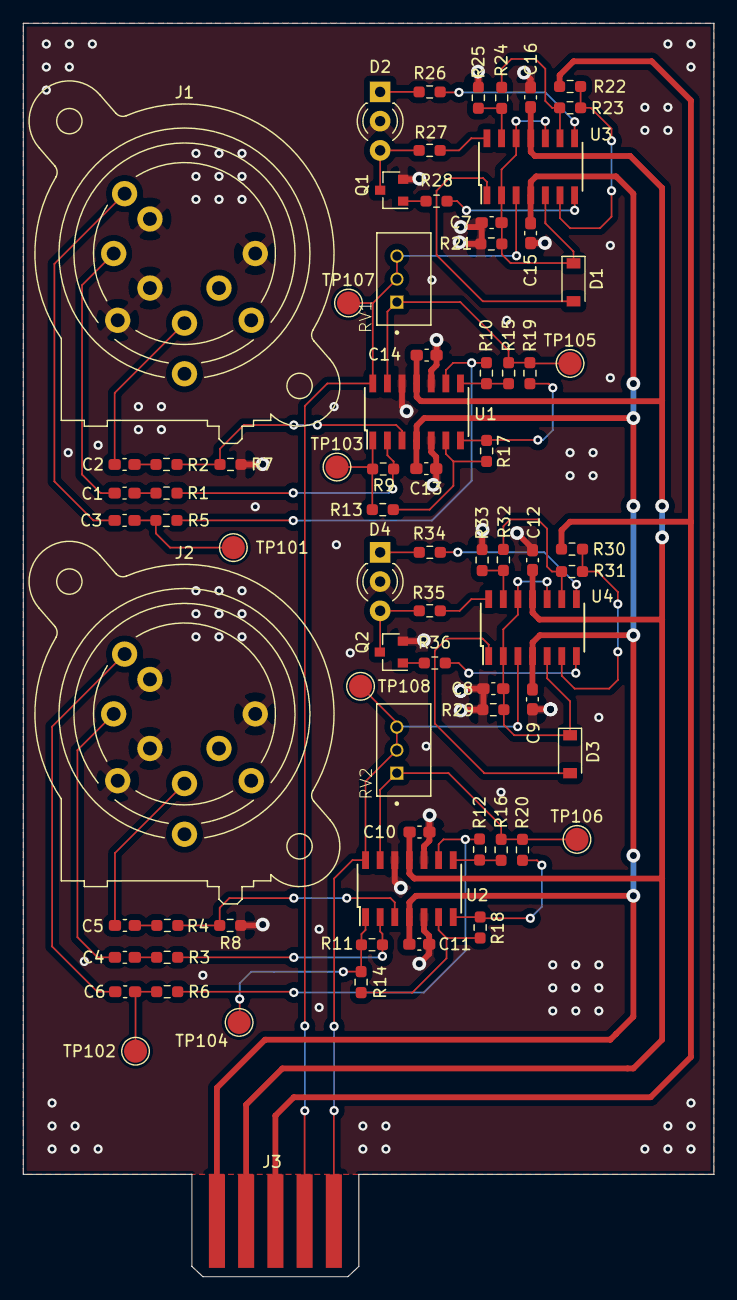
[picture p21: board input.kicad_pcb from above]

Board: 2 copper layers, 60.0 x 108.9 mm, 75 parts (0 on the bottom side), 56 nets.

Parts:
C1, C2, C4, C5: 4.7u; C_0603_1608Metric_Pad1.08x0.95mm_HandSolder
C3, C6, C7, C8: 10u; C_0603_1608Metric_Pad1.08x0.95mm_HandSolder
C9, C10, C11, C12, C13, C14, C15, C16: 100n; C_0603_1608Metric_Pad1.08x0.95mm_HandSolder
D1, D3: 1N4148; D_SOD-123
D2, D4: LED_Dual_ACA; LED_D3.0mm-3
J1, J2: XLR3_AudioJack3_Combo_Switch; Jack_XLR-6.35mm_Neutrik_NCJ9FI-V_Vertical
J3: Conn_02x05_Odd_Even; 345-010-521-201_Male
Q1, Q2: MMBTA42; SOT-23
R1, R2, R3, R4, R13, R14, R28, R36: 1k; R_0603_1608Metric_Pad0.98x0.95mm_HandSolder
R5, R6, R7, R8, R9, R10, R11, R12, R15, R16, R17, R18, R19, R20: 10k; R_0603_1608Metric_Pad0.98x0.95mm_HandSolder
R21, R29: 4.7k; R_0603_1608Metric_Pad0.98x0.95mm_HandSolder
R22, R30: 27k; R_0603_1608Metric_Pad0.98x0.95mm_HandSolder
R23, R31: 18k; R_0603_1608Metric_Pad0.98x0.95mm_HandSolder
R24, R32: 33k; R_0603_1608Metric_Pad0.98x0.95mm_HandSolder
R25, R33: 22k; R_0603_1608Metric_Pad0.98x0.95mm_HandSolder
R26, R27, R34, R35: 470; R_0603_1608Metric_Pad0.98x0.95mm_HandSolder
RV1, RV2: 50k; TE-6-440054-3
TP101, TP102, TP103, TP104, TP105, TP106, TP107, TP108: TestPoint; TestPoint_Pad_D2.0mm
U1, U2, U3, U4: TL074; TL074-SOIC-14

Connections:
+2V: J3.5, R22.1, R30.1
+12V: C9.1, C11.1, C13.1, C15.1, J3.1, U1.4, U2.4, U3.4, U4.4
-12V: C10.2, C12.2, C14.2, C16.2, J3.3, U1.11, U2.11, U3.11, U4.11
/CARRIER: J3.9, RV2.2, RV2.3, TP108.1, U2.14, U4.3
/PROGRAM: J3.7, RV1.2, RV1.3, TP107.1, U1.14, U3.3
GND: C7.2, C8.2, C9.2, C10.1, C11.2, C12.1, C13.2, C14.1, C15.2, C16.1, D2.2, D4.2, J1.1, J1.S, J1.SN, J1.TN, J2.1, J2.S, J2.SN, J2.TN, J3.2, J3.4, J3.6, J3.8, J3.10, Q1.2, Q2.2, R7.2, R8.2, R21.2, R25.2, R29.2, R33.2, U1.5, U1.10, U1.12, U2.5, U2.10, U2.12
unnamed: C1.1, R1.2
unnamed: C1.2, J1.2
unnamed: C2.1, R2.2
unnamed: C2.2, J1.3
unnamed: C3.1, R5.2, TP101.1
unnamed: C3.2, J1.T
unnamed: C4.1, R3.2
unnamed: C4.2, J2.2
unnamed: C5.1, R4.2
unnamed: C5.2, J2.3
unnamed: C6.1, R6.2, TP102.1
unnamed: C6.2, J2.T
unnamed: C7.1, D1.1, R21.1, U3.2, U3.5, U3.10, U3.12
unnamed: C8.1, D3.1, R29.1, U4.2, U4.5, U4.10, U4.12
unnamed: D1.2, U3.1
unnamed: D2.1, R26.1
unnamed: D2.3, Q1.3, R27.1
unnamed: D3.2, U4.1
unnamed: D4.1, R34.1
unnamed: D4.3, Q2.3, R35.1
unnamed: Q1.1, R28.2
unnamed: Q2.1, R36.2
unnamed: R1.1, R9.2, U1.2
unnamed: R2.1, R7.1, U1.3
unnamed: R4.1, R8.1, U2.3
unnamed: R10.1, R15.1, U1.8
unnamed: R5.1, R10.2, U1.9
unnamed: R11.1, R14.2, TP104.1, U2.1
unnamed: R3.1, R11.2, U2.2
unnamed: R12.1, R16.1, U2.8
unnamed: R6.1, R12.2, U2.9
unnamed: R13.1, R17.2, U1.6
unnamed: R9.1, R13.2, TP103.1, U1.1
unnamed: R14.1, R18.2, U2.6
unnamed: R15.2, R19.1, RV1.1, TP105.1, U1.13
unnamed: R16.2, R20.1, RV2.1, TP106.1, U2.13
unnamed: R17.1, R19.2, U1.7
unnamed: R18.1, R20.2, U2.7
unnamed: R22.2, R23.1, U3.6
unnamed: R23.2, R24.1, U3.9
unnamed: R24.2, R25.1, U3.13
unnamed: R26.2, U3.8
unnamed: R27.2, U3.14
unnamed: R28.1, U3.7
unnamed: R30.2, R31.1, U4.6
unnamed: R31.2, R32.1, U4.9
unnamed: R32.2, R33.1, U4.13
unnamed: R34.2, U4.8
unnamed: R35.2, U4.14
unnamed: R36.1, U4.7

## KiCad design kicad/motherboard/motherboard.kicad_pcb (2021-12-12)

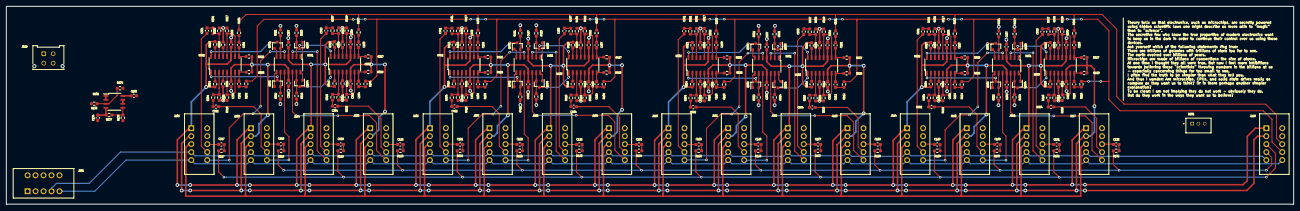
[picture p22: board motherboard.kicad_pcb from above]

Board: 2 copper layers, 410.0 x 63.0 mm, 271 parts (0 on the bottom side), 237 nets.

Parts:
C101, C102, C103, C104, C105, C106, C107, C108, C109, C110, C111, C112, C113, C114, C115, C116, C117, C118, C119, C120, C121, C122, C123, C124, C125, C126, C127, C128, C129, C130, C131, C132, C301, C302, C303, C304, C401, C402, C403, C404, C501, C502, C503, C504, C601, C602, C603, C604: 10u; C_0603_1608Metric_Pad1.08x0.95mm_HandSolder
C133, C134, C305, C306, C307, C308, C309, C310, C405, C406, C407, C408, C409, C410, C505, C506, C507, C508, C509, C510, C605, C606, C607, C608, C609, C610: 100n; C_0603_1608Metric_Pad1.08x0.95mm_HandSolder
D101: LED; TE-6-440054-3
J101, J102, J103, J104, J105, J106, J107, J108, J109, J110, J111, J112, J113, J114, J115, J116, J117, J118: Conn_02x05_Odd_Even; 345-010-521-201_Female
J119: Conn_02x02_Odd_Even; Molex_Micro-Fit_3.0_43045-0412_2x02_P3.00mm_Vertical
Q301, Q302, Q303, Q304, Q401, Q402, Q403, Q404, Q501, Q502, Q503, Q504, Q601, Q602, Q603, Q604: MMBTA92; SOT-23
R101, R102, R103, R104, R105, R106, R107, R108, R109, R110, R111, R112, R113, R114, R115, R116, R117, R118, R119, R120, R121, R122, R123, R124, R125, R126, R127, R128, R129, R130, R131, R132, R301, R304, R307, R310, R313, R314, R315, R316, R401, R404, R407, R410, R413, R414, R415, R416, R501, R504, R507, R510, R513, R514, R515, R516, R601, R604, R607, R610, R613, R614, R615, R616: 10k; R_0603_1608Metric_Pad0.98x0.95mm_HandSolder
R134, R137: 82k; R_0603_1608Metric_Pad0.98x0.95mm_HandSolder
R135, R136: 18k; R_0603_1608Metric_Pad0.98x0.95mm_HandSolder
R302, R303, R305, R306, R308, R309, R311, R312, R402, R403, R405, R406, R408, R409, R411, R412, R502, R503, R505, R506, R508, R509, R511, R512, R602, R603, R605, R606, R608, R609, R611, R612: 470; R_0603_1608Metric_Pad0.98x0.95mm_HandSolder
R317, R318, R319, R320, R325, R326, R327, R328, R417, R418, R419, R420, R425, R426, R427, R428, R517, R518, R519, R520, R525, R526, R527, R528, R617, R618, R619, R620, R625, R626, R627, R628: 33k; R_0603_1608Metric_Pad0.98x0.95mm_HandSolder
R321, R322, R323, R324, R421, R422, R423, R424, R521, R522, R523, R524, R621, R622, R623, R624: 2.2k; R_0603_1608Metric_Pad0.98x0.95mm_HandSolder
U101: TL072; TL072-SOIC-8
U301, U401, U501, U601: TL074; TL074-SOIC-14
U302, U303, U402, U403, U502, U503, U602, U603: LM13700; LM13700-SOIC-16

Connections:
+2V: J101.5, U101.1, U101.2
+12V: C133.1, C305.1, C307.1, C309.1, C405.1, C407.1, C409.1, C505.1, C507.1, C509.1, C605.1, C607.1, C609.1, D101.2, J101.1, J102.1, J103.1, J104.1, J105.1, J106.1, J107.1, J108.1, J109.1, J110.1, J111.1, J112.1, J113.1, J114.1, J115.1, J116.1, J117.1, J118.1, J119.1, R134.1, R313.2, R314.2, R315.2, R316.2, R413.2, R414.2, R415.2, R416.2, R513.2, R514.2, R515.2, R516.2, R613.2, R614.2, R615.2, R616.2, U101.8, U301.4, U302.11, U303.11, U401.4, U402.11, U403.11, U501.4, U502.11, U503.11, U601.4, U602.11, U603.11
-2V: J102.5, J103.5, J104.5, J105.5, J106.5, J107.5, J108.5, J109.5, J110.5, J111.5, J112.5, J113.5, J114.5, J115.5, J116.5, J117.5, U101.6, U101.7
-12V: C134.2, C306.2, C308.2, C310.2, C406.2, C408.2, C410.2, C506.2, C508.2, C510.2, C606.2, C608.2, C610.2, J101.3, J102.3, J103.3, J104.3, J105.3, J106.3, J107.3, J108.3, J109.3, J110.3, J111.3, J112.3, J113.3, J114.3, J115.3, J116.3, J117.3, J118.3, J119.4, R137.2, R325.1, R326.1, R327.1, R328.1, R425.1, R426.1, R427.1, R428.1, R525.1, R526.1, R527.1, R528.1, R625.1, R626.1, R627.1, R628.1, U101.4, U301.11, U302.6, U303.6, U401.11, U402.6, U403.6, U501.11, U502.6, U503.6, U601.11, U602.6, U603.6
/CARRIER: J101.9, J102.9, J103.9, J104.9, J105.9, J106.9, J107.9, J108.9, J109.9, J110.9, J111.9, J112.9, J113.9, J114.9, J115.9, J116.9, J117.9, J118.10
/CARRIER_BAND_1: C301.2, J102.8
/CARRIER_BAND_2: C302.2, J103.8
/CARRIER_BAND_3: C303.2, J104.8
/CARRIER_BAND_4: C304.2, J105.8
/CARRIER_BAND_5: C401.2, J106.8
/CARRIER_BAND_6: C402.2, J107.8
/CARRIER_BAND_7: C403.2, J108.8
/CARRIER_BAND_8: C404.2, J109.8
/CARRIER_BAND_9: C501.2, J110.8
/CARRIER_BAND_10: C502.2, J111.8
/CARRIER_BAND_11: C503.2, J112.8
/CARRIER_BAND_12: C504.2, J113.8
/CARRIER_BAND_13: C601.2, J114.8
/CARRIER_BAND_14: C602.2, J115.8
/CARRIER_BAND_15: C603.2, J116.8
/CARRIER_BAND_16: C604.2, J117.8
/MOD_CARRIER_BANDS_LEFT: J118.6, R101.1, R103.1, R105.1, R107.1, R109.1, R111.1, R113.1, R115.1
/MOD_CARRIER_BANDS_RIGHT: J118.8, R102.1, R104.1, R106.1, R108.1, R110.1, R112.1, R114.1, R116.1
/MOD_CARRIER_BAND_1: C101.2, R325.2, U302.9
/MOD_CARRIER_BAND_2: C102.2, R326.2, U302.8
/MOD_CARRIER_BAND_3: C103.2, R327.2, U303.9
/MOD_CARRIER_BAND_4: C104.2, R328.2, U303.8
/MOD_CARRIER_BAND_5: C105.2, R425.2, U402.9
/MOD_CARRIER_BAND_6: C106.2, R426.2, U402.8
/MOD_CARRIER_BAND_7: C107.2, R427.2, U403.9
/MOD_CARRIER_BAND_8: C108.2, R428.2, U403.8
/MOD_CARRIER_BAND_9: C109.2, R525.2, U502.9
/MOD_CARRIER_BAND_10: C110.2, R526.2, U502.8
/MOD_CARRIER_BAND_11: C111.2, R527.2, U503.9
/MOD_CARRIER_BAND_12: C112.2, R528.2, U503.8
/MOD_CARRIER_BAND_13: C113.2, R625.2, U602.9
/MOD_CARRIER_BAND_14: C114.2, R626.2, U602.8
/MOD_CARRIER_BAND_15: C115.2, R627.2, U603.9
/MOD_CARRIER_BAND_16: C116.2, R628.2, U603.8
/PROGRAM: J101.7, J102.7, J103.7, J104.7, J105.7, J106.7, J107.7, J108.7, J109.7, J110.7, J111.7, J112.7, J113.7, J114.7, J115.7, J116.7, J117.7, J118.9
/PROGRAM_BANDS_LEFT: J118.5, R117.1, R119.1, R121.1, R123.1, R125.1, R127.1, R129.1, R131.1
/PROGRAM_BANDS_RIGHT: J118.7, R118.1, R120.1, R122.1, R124.1, R126.1, R128.1, R130.1, R132.1
/PROGRAM_BAND_1: C117.2, J102.6
/PROGRAM_BAND_2: C118.2, J103.6
/PROGRAM_BAND_3: C119.2, J104.6
/PROGRAM_BAND_4: C120.2, J105.6
/PROGRAM_BAND_5: C121.2, J106.6
/PROGRAM_BAND_6: C122.2, J107.6
/PROGRAM_BAND_7: C123.2, J108.6
/PROGRAM_BAND_8: C124.2, J109.6
/PROGRAM_BAND_9: C125.2, J110.6
/PROGRAM_BAND_10: C126.2, J111.6
/PROGRAM_BAND_11: C127.2, J112.6
/PROGRAM_BAND_12: C128.2, J113.6
/PROGRAM_BAND_13: C129.2, J114.6
/PROGRAM_BAND_14: C130.2, J115.6
/PROGRAM_BAND_15: C131.2, J116.6
/PROGRAM_BAND_16: C132.2, J117.6
/PROGRAM_ENV_1: J102.10, U301.5
/PROGRAM_ENV_2: J103.10, U301.10
/PROGRAM_ENV_3: J104.10, U301.3
/PROGRAM_ENV_4: J105.10, U301.12
/PROGRAM_ENV_5: J106.10, U401.5
/PROGRAM_ENV_6: J107.10, U401.10
/PROGRAM_ENV_7: J108.10, U401.3
/PROGRAM_ENV_8: J109.10, U401.12
/PROGRAM_ENV_9: J110.10, U501.5
/PROGRAM_ENV_10: J111.10, U501.10
/PROGRAM_ENV_11: J112.10, U501.3
/PROGRAM_ENV_12: J113.10, U501.12
/PROGRAM_ENV_13: J114.10, U601.5
/PROGRAM_ENV_14: J115.10, U601.10
/PROGRAM_ENV_15: J116.10, U601.3
/PROGRAM_ENV_16: J117.10, U601.12
GND: C133.2, C134.1, C305.2, C306.1, C307.2, C308.1, C309.2, C310.1, C405.2, C406.1, C407.2, C408.1, C409.2, C410.1, C505.2, C506.1, C507.2, C508.1, C509.2, C510.1, C605.2, C606.1, C607.2, C608.1, C609.2, C610.1, J101.2, J101.4, J101.6, J101.8, J101.10, J102.2, J102.4, J103.2, J103.4, J104.2, J104.4, J105.2, J105.4, J106.2, J106.4, J107.2, J107.4, J108.2, J108.4, J109.2, J109.4, J110.2, J110.4, J111.2, J111.4, J112.2, J112.4, J113.2, J113.4, J114.2, J114.4, J115.2, J115.4, J116.2, J116.4, J117.2, J117.4, J118.2, J118.4, J119.2, J119.3, R135.2, R136.1, R302.2, R303.2, R305.2, R306.2, R308.2, R309.2, R311.2, R312.2, R317.1, R318.1, R319.1, R320.1, R321.1, R322.1, R323.1, R324.1, R402.2, R403.2, R405.2, R406.2, R408.2, R409.2, R411.2, R412.2, R417.1, R418.1, R419.1, R420.1, R421.1, R422.1, R423.1, R424.1, R502.2, R503.2, R505.2, R506.2, R508.2, R509.2, R511.2, R512.2, R517.1, R518.1, R519.1, R520.1, R521.1, R522.1, R523.1, R524.1, R602.2, R603.2, R605.2, R606.2, R608.2, R609.2, R611.2, R612.2, R617.1, R618.1, R619.1, R620.1, R621.1, R622.1, R623.1, R624.1
unnamed: C101.1, R101.2
unnamed: C102.1, R102.2
unnamed: C103.1, R103.2
unnamed: C104.1, R104.2
unnamed: C105.1, R105.2
unnamed: C106.1, R106.2
unnamed: C107.1, R107.2
unnamed: C108.1, R108.2
unnamed: C109.1, R109.2
unnamed: C110.1, R110.2
unnamed: C111.1, R111.2
unnamed: C112.1, R112.2
unnamed: C113.1, R113.2
unnamed: C114.1, R114.2
unnamed: C115.1, R115.2
unnamed: C116.1, R116.2
unnamed: C117.1, R117.2
unnamed: C118.1, R118.2
unnamed: C119.1, R119.2
unnamed: C120.1, R120.2
unnamed: C121.1, R121.2
unnamed: C122.1, R122.2
unnamed: C123.1, R123.2
unnamed: C124.1, R124.2
unnamed: C125.1, R125.2
unnamed: C126.1, R126.2
unnamed: C127.1, R127.2
unnamed: C128.1, R128.2
unnamed: C129.1, R129.2
unnamed: C130.1, R130.2
unnamed: C131.1, R131.2
unnamed: C132.1, R132.2
unnamed: C301.1, R301.2
unnamed: C302.1, R304.2
unnamed: C303.1, R307.2
unnamed: C304.1, R310.2
unnamed: C401.1, R401.2
unnamed: C402.1, R404.2
unnamed: C403.1, R407.2
unnamed: C404.1, R410.2
unnamed: C501.1, R501.2
unnamed: C502.1, R504.2
unnamed: C503.1, R507.2
unnamed: C504.1, R510.2
unnamed: C601.1, R601.2
unnamed: C602.1, R604.2
unnamed: C603.1, R607.2
unnamed: C604.1, R610.2
unnamed: Q301.1, U301.7
unnamed: Q301.2, R321.2, U301.6
unnamed: Q301.3, U302.16
unnamed: Q302.1, U301.8
unnamed: Q302.2, R322.2, U301.9
unnamed: Q302.3, U302.1
unnamed: Q303.1, U301.1
unnamed: Q303.2, R323.2, U301.2
unnamed: Q303.3, U303.16
unnamed: Q304.1, U301.14
unnamed: Q304.2, R324.2, U301.13
unnamed: Q304.3, U303.1
unnamed: Q401.1, U401.7
unnamed: Q401.2, R421.2, U401.6
unnamed: Q401.3, U402.16
unnamed: Q402.1, U401.8
unnamed: Q402.2, R422.2, U401.9
unnamed: Q402.3, U402.1
unnamed: Q403.1, U401.1
unnamed: Q403.2, R423.2, U401.2
unnamed: Q403.3, U403.16
unnamed: Q404.1, U401.14
unnamed: Q404.2, R424.2, U401.13
unnamed: Q404.3, U403.1
unnamed: Q501.1, U501.7
unnamed: Q501.2, R521.2, U501.6
unnamed: Q501.3, U502.16
unnamed: Q502.1, U501.8
unnamed: Q502.2, R522.2, U501.9
unnamed: Q502.3, U502.1
unnamed: Q503.1, U501.1
unnamed: Q503.2, R523.2, U501.2
unnamed: Q503.3, U503.16
unnamed: Q504.1, U501.14
unnamed: Q504.2, R524.2, U501.13
unnamed: Q504.3, U503.1
unnamed: Q601.1, U601.7
unnamed: Q601.2, R621.2, U601.6
unnamed: Q601.3, U602.16
unnamed: Q602.1, U601.8
unnamed: Q602.2, R622.2, U601.9
unnamed: Q602.3, U602.1
unnamed: Q603.1, U601.1
unnamed: Q603.2, R623.2, U601.2
unnamed: Q603.3, U603.16
unnamed: Q604.1, U601.14
unnamed: Q604.2, R624.2, U601.13
unnamed: Q604.3, U603.1
unnamed: R134.2, R135.1, U101.3
unnamed: R136.2, R137.1, U101.5
unnamed: R301.1, R302.1, U302.14
unnamed: R303.1, U302.13
unnamed: R304.1, R305.1, U302.3
unnamed: R306.1, U302.4
unnamed: R307.1, R308.1, U303.14
unnamed: R309.1, U303.13
unnamed: R310.1, R311.1, U303.3
unnamed: R312.1, U303.4
unnamed: R313.1, U302.15
unnamed: R314.1, U302.2
unnamed: R315.1, U303.15
unnamed: R316.1, U303.2
unnamed: R317.2, U302.10, U302.12
unnamed: R318.2, U302.5, U302.7
unnamed: R319.2, U303.10, U303.12
unnamed: R320.2, U303.5, U303.7
unnamed: R401.1, R402.1, U402.14
unnamed: R403.1, U402.13
unnamed: R404.1, R405.1, U402.3
unnamed: R406.1, U402.4
unnamed: R407.1, R408.1, U403.14
unnamed: R409.1, U403.13
unnamed: R410.1, R411.1, U403.3
unnamed: R412.1, U403.4
unnamed: R413.1, U402.15
unnamed: R414.1, U402.2
unnamed: R415.1, U403.15
unnamed: R416.1, U403.2
unnamed: R417.2, U402.10, U402.12
unnamed: R418.2, U402.5, U402.7
unnamed: R419.2, U403.10, U403.12
unnamed: R420.2, U403.5, U403.7
unnamed: R501.1, R502.1, U502.14
unnamed: R503.1, U502.13
unnamed: R504.1, R505.1, U502.3
unnamed: R506.1, U502.4
unnamed: R507.1, R508.1, U503.14
unnamed: R509.1, U503.13
unnamed: R510.1, R511.1, U503.3
unnamed: R512.1, U503.4
unnamed: R513.1, U502.15
unnamed: R514.1, U502.2
unnamed: R515.1, U503.15
unnamed: R516.1, U503.2
unnamed: R517.2, U502.10, U502.12
unnamed: R518.2, U502.5, U502.7
unnamed: R519.2, U503.10, U503.12
unnamed: R520.2, U503.5, U503.7
unnamed: R601.1, R602.1, U602.14
unnamed: R603.1, U602.13
unnamed: R604.1, R605.1, U602.3
unnamed: R606.1, U602.4
unnamed: R607.1, R608.1, U603.14
unnamed: R609.1, U603.13
unnamed: R610.1, R611.1, U603.3
unnamed: R612.1, U603.4
unnamed: R613.1, U602.15
unnamed: R614.1, U602.2
unnamed: R615.1, U603.15
unnamed: R616.1, U603.2
unnamed: R617.2, U602.10, U602.12
unnamed: R618.2, U602.5, U602.7
unnamed: R619.2, U603.10, U603.12
unnamed: R620.2, U603.5, U603.7

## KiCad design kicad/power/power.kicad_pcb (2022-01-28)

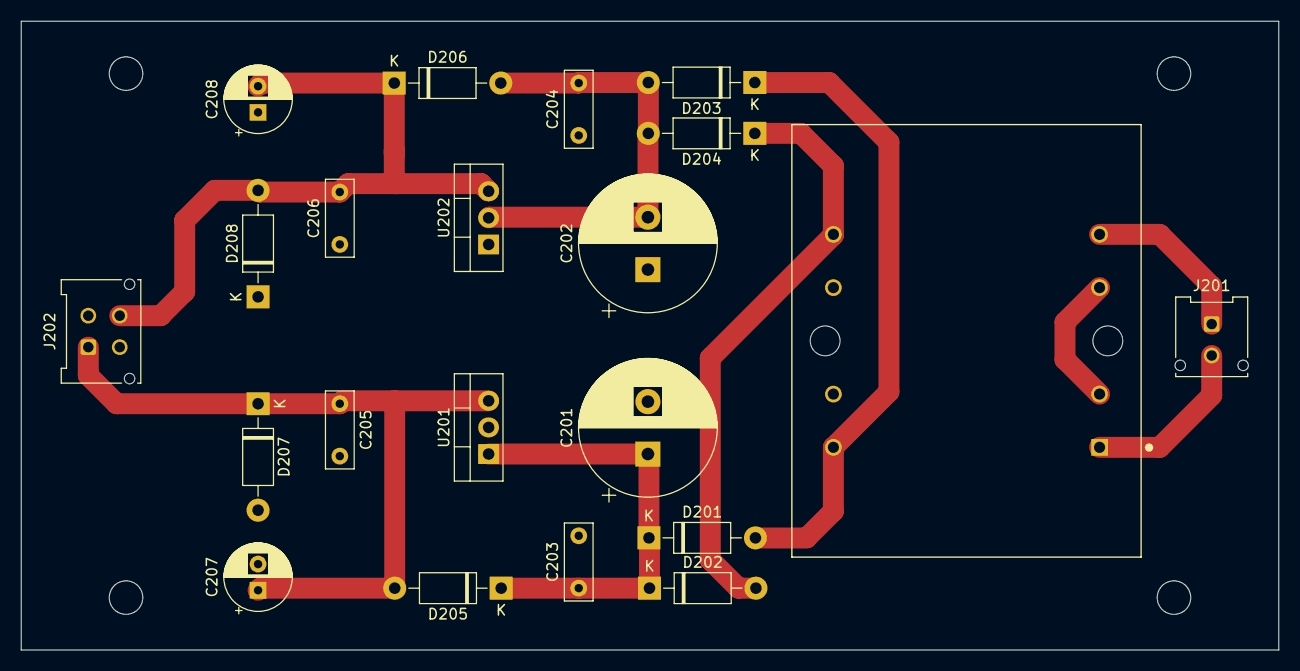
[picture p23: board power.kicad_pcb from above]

Board: 2 copper layers, 120.0 x 60.0 mm, 21 parts (0 on the bottom side), 10 nets.

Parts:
C201, C202: 2200u; CP_Radial_D13.0mm_P5.00mm
C203, C204, C205, C206: 100n; C_Rect_L7.2mm_W2.5mm_P5.00mm_FKS2_FKP2_MKS2_MKP2
C207, C208: 100u; CP_Radial_D6.3mm_P2.50mm
D201, D202, D203, D204, D205, D206, D207, D208: 1N4002; D_DO-41_SOD81_P10.16mm_Horizontal
J201: Conn_01x02_Female; Molex_Micro-Fit_3.0_43045-0212_2x01_P3.00mm_Vertical
J202: Conn_02x02_Odd_Even; Molex_Micro-Fit_3.0_43045-0412_2x02_P3.00mm_Vertical
T201: VPP36-140; XFMR_VPP36-140
U201: uA7812; TO-220-3_Vertical
U202: uA7912; TO-220-3_Vertical

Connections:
+12V: C205.1, C207.1, D205.2, D207.1, J202.1, U201.3
-12V: C206.2, C208.2, D206.1, D208.2, J202.4, U202.3
GND: C201.2, C202.1, C203.2, C204.1, C205.2, C206.1, C207.2, C208.1, D207.2, D208.1, J202.2, J202.3, T201.9, T201.10, U201.2, U202.1
unnamed: C201.1, C203.1, D201.1, D202.1, D205.1, U201.1
unnamed: C202.2, C204.2, D203.2, D204.2, D206.2, U202.2
unnamed: D201.2, D203.1, T201.7
unnamed: D202.2, D204.1, T201.12
unnamed: J201.1, T201.6
unnamed: J201.2, T201.1
unnamed: T201.3, T201.4

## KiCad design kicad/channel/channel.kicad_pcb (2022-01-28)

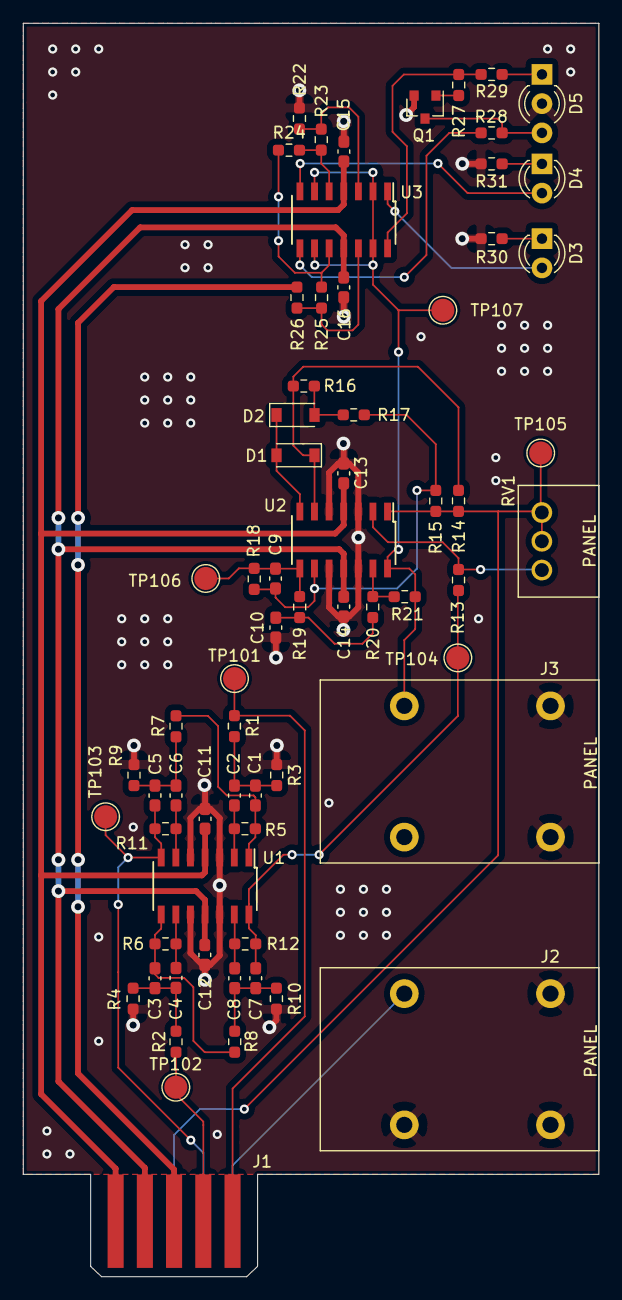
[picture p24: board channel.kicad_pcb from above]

Board: 2 copper layers, 50.0 x 108.9 mm, 67 parts (0 on the bottom side), 42 nets.

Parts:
C1, C2, C3, C4, C5, C6, C7, C8: X; C_0603_1608Metric_Pad1.08x0.95mm_HandSolder
C9, C10: 680n; C_0603_1608Metric_Pad1.08x0.95mm_HandSolder
C11, C12, C13, C14, C15, C16: 100n; C_0603_1608Metric_Pad1.08x0.95mm_HandSolder
D1, D2: 1N4148; D_SOD-123
D3, D4: LED; LED_D3.0mm
D5: LED_Dual_ACA; LED_D3.0mm-3
J1: Conn_02x05_Odd_Even; 345-010-521-201_Male
J2, J3: AudioJack2_Switch; Amphenol_ACJM-MHDRM
Q1: MMBTA42; SOT-23
R1, R2: 33k; R_0603_1608Metric_Pad0.98x0.95mm_HandSolder
R3, R4: 2k; R_0603_1608Metric_Pad0.98x0.95mm_HandSolder
R5, R6: 200k; R_0603_1608Metric_Pad0.98x0.95mm_HandSolder
R7, R8: 20k; R_0603_1608Metric_Pad0.98x0.95mm_HandSolder
R9, R10: 1.2k; R_0603_1608Metric_Pad0.98x0.95mm_HandSolder
R11, R12: 120k; R_0603_1608Metric_Pad0.98x0.95mm_HandSolder
R13: 50k; R_0603_1608Metric_Pad0.98x0.95mm_HandSolder
R14, R15, R16, R17, R18, R19: 10k; R_0603_1608Metric_Pad0.98x0.95mm_HandSolder
R20, R21: 100k; R_0603_1608Metric_Pad0.98x0.95mm_HandSolder
R22: 4.7k; R_0603_1608Metric_Pad0.98x0.95mm_HandSolder
R23: 18k; R_0603_1608Metric_Pad0.98x0.95mm_HandSolder
R24, R25, R26: 27k; R_0603_1608Metric_Pad0.98x0.95mm_HandSolder
R27: 1k; R_0603_1608Metric_Pad0.98x0.95mm_HandSolder
R28, R29, R30, R31: 470; R_0603_1608Metric_Pad0.98x0.95mm_HandSolder
RV1: 100k; Bourns_PTD901-2015K-A104
TP101, TP102, TP103, TP104, TP105, TP106, TP107: TestPoint; TestPoint_Pad_D2.0mm
U1, U2, U3: TL074; TL074-SOIC-14

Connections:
+12V: C11.1, C13.1, C15.1, J1.1, U1.4, U2.4, U3.4
-2V: J1.5, R26.2
-12V: C12.2, C14.2, C16.2, J1.3, U1.11, U2.11, U3.11
/BAND_LEDS/IN: J3.T, R21.1, TP107.1, U2.14, U3.2, U3.6, U3.9, U3.13
/CARRIER: J1.9, R1.2, TP101.1
/CARRIER_BAND: C5.1, J1.8, R11.2, TP103.1, U1.7
/PROGRAM: J1.7, R2.2, TP102.1
/PROGRAM_BAND: J1.6, R14.2, R15.2, RV1.2, RV1.3, TP105.1, U2.1
/PROGRAM_ENV: J1.10, J2.T
GND: C10.1, C11.2, C12.1, C13.2, C14.1, C15.2, C16.1, D5.2, J1.2, J1.4, J2.S, J2.SN, J2.TN, J3.S, J3.SN, Q1.2, R3.1, R4.1, R9.1, R10.1, R22.1, R30.1, R31.1, U1.3, U1.5, U1.10, U1.12, U2.3, U2.5, U2.10, U2.12
unnamed: C1.1, R5.2, R7.2, U1.1
unnamed: C1.2, C2.2, R1.1, R3.2
unnamed: C2.1, R5.1, U1.2
unnamed: C3.1, R6.2, R8.2, U1.8
unnamed: C3.2, C4.2, R2.1, R4.2
unnamed: C4.1, R6.1, U1.9
unnamed: C5.2, C6.2, R7.1, R9.2
unnamed: C6.1, R11.1, U1.6
unnamed: C7.1, R12.2, R13.2, TP104.1, U1.14
unnamed: C7.2, C8.2, R8.1, R10.2
unnamed: C8.1, R12.1, U1.13
unnamed: C9.1, R18.1, R19.2, TP106.1, U2.8
unnamed: C9.2, R15.1, R17.1, R18.2, U2.9
unnamed: C10.2, R19.1, R20.2
unnamed: D1.1, R14.1, R16.2, U2.6
unnamed: D1.2, D2.1, U2.7
unnamed: D2.2, R16.1, R17.2
unnamed: D3.1, R30.2
unnamed: D3.2, U3.1
unnamed: D4.1, R31.2
unnamed: D4.2, U3.7
unnamed: D5.1, R29.1
unnamed: D5.3, Q1.3, R28.1
unnamed: Q1.1, R27.1
unnamed: R13.1, RV1.1, U2.2
unnamed: R20.1, R21.2, U2.13
unnamed: R22.2, R23.1, U3.3
unnamed: R23.2, R24.1, U3.5
unnamed: R24.2, R25.1, U3.10
unnamed: R25.2, R26.1, U3.12
unnamed: R27.2, R29.2, U3.14
unnamed: R28.2, U3.8

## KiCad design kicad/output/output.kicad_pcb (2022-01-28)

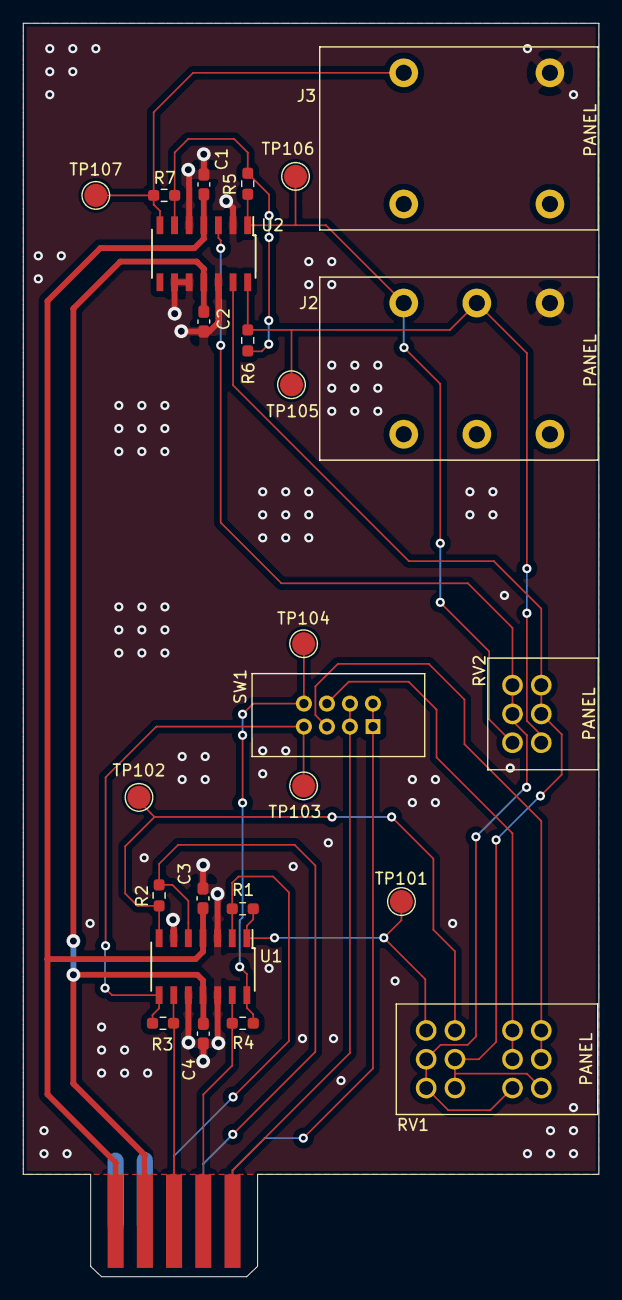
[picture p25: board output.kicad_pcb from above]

Board: 2 copper layers, 50.0 x 108.9 mm, 26 parts (0 on the bottom side), 21 nets.

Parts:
C1, C2, C3, C4: 100n; C_0603_1608Metric_Pad1.08x0.95mm_HandSolder
J1: Conn_02x05_Odd_Even; 345-010-521-201_Male
J2: AudioJack3_Switch; Amphenol_ACJS-MHDRM
J3: AudioJack2_Switch; Amphenol_ACJM-MHDRM
R1, R2, R3, R4, R5, R6, R7: 10k; R_0603_1608Metric_Pad0.98x0.95mm_HandSolder
RV1: 10k; Bourns_PTD904-2020K-B103
RV2: 20k; Bourns_PTD902-2020K-A203
SW1: SW_DP3T; Hirose-DF51A-8DP-2DSA
TP101, TP102, TP103, TP104, TP105, TP106, TP107: TestPoint; TestPoint_Pad_D2.0mm
U1, U2: TL074; TL074-SOIC-14

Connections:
+12V: C1.1, C3.1, J1.1, U1.4, U2.4
-12V: C2.2, C4.2, J1.3, U1.11, U2.11
/CARRIER: J1.10, SW1.1, SW1.5
/FEEDTHROUGH_LEFT: RV1.R22, RV1.R23, SW1.7
/FEEDTHROUGH_RIGHT: RV1.R12, RV1.R13, SW1.3
/MOD_CARRIER_BANDS_LEFT: J1.6, R1.2, U1.2
/MOD_CARRIER_BANDS_LEFT_BUFFERED: R1.1, RV1.R43, TP101.1, U1.1
/MOD_CARRIER_BANDS_RIGHT: J1.8, R2.2, U1.5
/MOD_CARRIER_BANDS_RIGHT_BUFFERED: R2.1, RV1.R33, TP102.1, U1.7
/PROGRAM: J1.9, SW1.2, SW1.6
/PROGRAM_BANDS_LEFT: J1.5, R3.2, U1.9
/PROGRAM_BANDS_LEFT_BUFFERED: R3.1, SW1.4, TP103.1, U1.8
/PROGRAM_BANDS_RIGHT: J1.7, R4.2, U1.13
/PROGRAM_BANDS_RIGHT_BUFFERED: R4.1, SW1.8, TP104.1, U1.14
GND: C1.2, C2.1, C3.2, C4.1, J1.2, J1.4, J2.S, J3.S, U1.3, U1.6, U1.10, U1.12, U2.2, U2.5, U2.9, U2.10, U2.12
unnamed: J2.R, R6.2, RV2.4, TP105.1, U2.14
unnamed: J2.T, R5.1, RV2.1, TP106.1, U2.1
unnamed: J3.T, R7.2, TP107.1, U2.7
unnamed: R5.2, R6.1, R7.1, U2.6
unnamed: RV1.R11, RV1.R31, RV1.R32, RV2.5, RV2.6, U2.13
unnamed: RV1.R21, RV1.R41, RV1.R42, RV2.2, RV2.3, U2.3

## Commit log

2021-11-23 Routed all the hard parts
    [MOTHERBOARD.kicad_pcb]
2021-12-12 New series resistor values for LEDs
    [BAND_LEDS.sch, INPUT_LEDS.sch, MOTHERBOARD.kicad_pcb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]
2022-01-28 Major folder restructuring
    [BAND_LEDS.sch, CHANNEL_BOARD.kicad_pcb, CHANNEL_BOARD.sch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]
2022-01-28 PDFs of schematics
